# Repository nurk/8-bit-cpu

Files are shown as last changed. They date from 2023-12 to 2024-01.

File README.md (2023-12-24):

This repository contains my design of the Ben Eater 8-bit computer.  I call it an 8-CPU instead of a computer because to me it feels more like a CPU.

If you were to do a checkout of this, it is basically a KiCad project folder.  It will not contain all the symbols I used because the ones I designed I made global in KiCad, but I added a PDF of all the schematics.

You will also find my instruction set, the code to program the EEPROM's and the code to program the CPU which includes my test programs.

Below is a little badly written story of my journey.

## 8-bit CPU
I have always been intrigued by electronics by have never done anything with it.

A while back I found a video series by Ben Eater about building an 8-bit computer on breadboards ([YouTube](https://www.youtube.com/playlist?list=PLowKtXNTBypGqImE405J2565dvjafglHU)).  Watching the series I learned a lot about how CPU's (could) work and was really fascinated.  It all did not seem that complicated.

So after thinking about it for a while and checking my finances (It is not really cheap) I decided to build a variation of it.   But first I did some research and set some goals.

The research taught me that I should not skimp on breadboard quality.  There are a lot of people that write about this and the breadboards from BusBoard Prototype Systems seem to be one of the best.

Next I started digging into what types of 74 series logic chips there are.  I learned that the 74LS series that Ben uses are TTL logic chips but they are rather power hungry.  I decided I wanted to go with CMOS logic chips because they are more efficient.  In the end I went for 74HCT chips.  They are CMOS chips with TTL level support.  I went for this because I don't really know anything about this and I was not sure if I needed TTL level support in some parts.

So the chip series was decided and the breadboard brand was decided, now I needed a way to get all these things.  I started searching for those online and found the usual suspects: 
* Farnell
* Digikey
* Mouser
* ...

I live in Belgium so delivery costs, import taxes and VAT were important.  After a test order from [Mouser](https://www.mouser.be/) I learned that they take care of the VAT and the import taxes, and when you order over 50 EUR (excluding VAT) the delivery is free.  Just don't get caught at checkout because the prices on the site are without VAT.

I would also need a power supply.  I did not want to use a cut open USB cable but wanted some extra features.
* The device needed a global on/off switch
* I needed to be able to toggle the output on or off 
* Obviously the voltage should be settable
* The amperage should be limited
* I wanted over current protection so the output would be turned off if my creation would draw more than the set amps

On Amazon I found this [device](https://www.amazon.nl/dp/B0C1SMSW9F?ref=ppx_yo2ov_dt_b_product_details&th=1) that had all the features I wanted and it was not out of my budget.

Amazon was also used to buy the [wires](https://www.amazon.com.be/dp/B07V5FVSYL?psc=1&ref=ppx_yo2ov_dt_b_product_details) and initially some [resistors](https://www.amazon.com.be/dp/B0967TG6XR?ref=ppx_yo2ov_dt_b_product_details&th=1).  The wires were great and I ordered multiple of those because it seems this thing needs a lot of wire.  The resistors I hated and did not use.  The legs have a diameter of 0.3 mm which is just too thin.  When you want to insert them into a breadboard they just bend.  The resistors eventually also came from Mouser.

Next up, the goals of this build.
* I wanted a schematic of my build so I learned to use [KiCad](https://www.kicad.org/)
* Have more RAM so I could use all 8 address bits
* Have the RAM split so the first 128 bytes are for application memory and second 128 bytes are for data memory.  I did not want my application to overwrite itself
* Have an X register with +1 / -1 feature to enable specific loops and have it set the carry flag and zero flag
* Have a Stack
* Do not leave any input pins floating
* Have a 220 Ohm resistor on each LED (this includes each segment of the 7-segment display)
* Have a 100nF decoupling capacitor for each chip

The 220 Ohm resistor on each LED really made me think about component placement.  It dictated the layout on the breadboards.  Unlike what Ben does in his videos I could not just go from an output pin to ground.

After all the orders arrived I started building my CPU module by module in the order of the videos.  I would first design each module in KiCad and use my design to build it on breadboards.

While building I initially used 10k Ohm resistors to either pull-up or pull-down control signal pins.  That way I could use a jumper wire to switch its state without the pin being floating during the transition.  (The resistors were removed after wiring up the control signals.) The different modules were tested individually once they were finished.

When building the output module I noticed I did not order any 74HCT273 chips.  So I changed my design to use what I had which were 74HCT173 D-type flip flops.  In hindsight this seems to be a blessing in disguise because there seems to be a design issue with using the 74HCT273 as can be seen [here](https://www.youtube.com/playlist?list=PLyHdG0fm3K1j8sfvvdIarTFXVcFDdoBYp).

After finishing the clock, program counter, a register, alu, b register, output, ram and instruction register I decided to combine them and wire them up to the bus.  This is were I got hit with my first problem.

Whenever there were more than 4 LED's active in the RAM value and I would change the RAM output control signal (high to low or low to high) the RAM address register would reset.  I searched for hours what the cause could be but never figured it out.  I rewired stuff, replaced chips, disconnected modules from the bus, added pull-up and pull-down resisters, ... but everything stayed the same.  Motivation really sank so drastic measures needed to be taken.  Given the RAM address gets loaded by the program counter initially I decided I did not need a reset there and removed the reset line and tied the pins to ground.  *Problem solved*.

Next I built the last 4 modules: control logic, CPU flags, X register and stack.  When they were done I wired up everything.  Guess what, things did not work as expected.  Some of the problems I saw:
* The A register would reset randomly
* The X register would reset randomly
* The X register would load data from the bus at random points
* The X register would increment and decrement randomly
* The stack would increment and decrement randomly
* RAM not always writing

Those dreaded random resets were spreading.  Given I have no oscilloscope I could not really see what was going on with reset line but after some mental gymnastics I figured there must be some noise getting to the reset line.  Given I know nothing about electronics I started trying things.  

When I put a 10nF capacitor on the reset line close to the reset pin and ground of the A register it no longer did the random reset but the button to reset everything still worked.  I did the same with the X register and wired up the reset for the RAM address again with a 10nF capacitor.  No more random resets.  I still don't know why this is happening but it is fixed.  *Problem solved*.

Next up were the random actions in the X register and stack.  After searching the internet I found out that when you change the address on an EEPROM there is a period of time where the data is invalid (this is also in the datasheet).  This shows itself by data pins going high or low randomly during the invalid period.  This was triggering the random actions.

The first fix was not to trigger the load of the X register by just using an inverted control signal.  I used the non inverted control signal and the clock through a NAND gate to trigger the load.  This way the loading is tied to a clock transition which is in line with the rest of the design.  This made things better but did not solve everything.

After some more searching on the internet I found a post where someone explained that the entire computer reacts to the rising edge of the clock.  This includes the instruction register and the CPU flags which trigger address changes.  If you were to change the address on the falling edge of the clock the 'blips' on the EEPROM output would not matter.

I first thought about using the inverted clock for the instruction register and the CPU flags but decided against it.  I was not sure if this would have side effects.  Given I had some room below the instruction register I decided to add two more 74HCT173 D-type flip flops to latch the instruction register and the CPU flags on the falling edge of each clock.  These latched values are used as the address lines for the EEPROM's.  This solved all the problems of random actions occurring.

Lastly there was the problem of the RAM not always writing.  I was aware of issues with the RC circuit Ben has in his original design on the clock for the RAM input.  I already put in a diode to prevent back feeding any voltage as the capacitor discharges but I was still suspicious.  Given writing ram works with a push button in programming mode, which does not have an RC circuit on it, I figured it might work without.  After removing the RC circuit and just passing in the clock everything worked.

I now have an 8-bit breadboard CPU which supports addition, subtraction, push, pop, subroutines, ...

#### Some random bits:

I can program the CPU using the dip switches but that got old really quickly.  I wrote a little Arduino application that could program the CPU.  I just hook up the ground, the address lines, the data lines and write signal to the breadboard from an [Arduino Nano Every](https://store.arduino.cc/products/arduino-nano-every).  This saves a lot of time and does not discourage me from making changes and retesting.

On the internet there are many posts that say you have to add a lot of bulk capacitors to the breadboards in order to make it stable.  My CPU does not seem to need it.  It could be the quality of the breadboards, the fact that I used 74HCT chips or the quality of the power supply.  When running my Fibonacci program it draws a maximum of 350 mA.

I used an alternative to the EEPROM programmer designed by Ben.  Given I used an Arduino Nano Every, which has more digital pins, I did not have to combine the write signal into the shift registers.  I did have to rewire it because my EEPROM's did not seems to have the content I expected. 

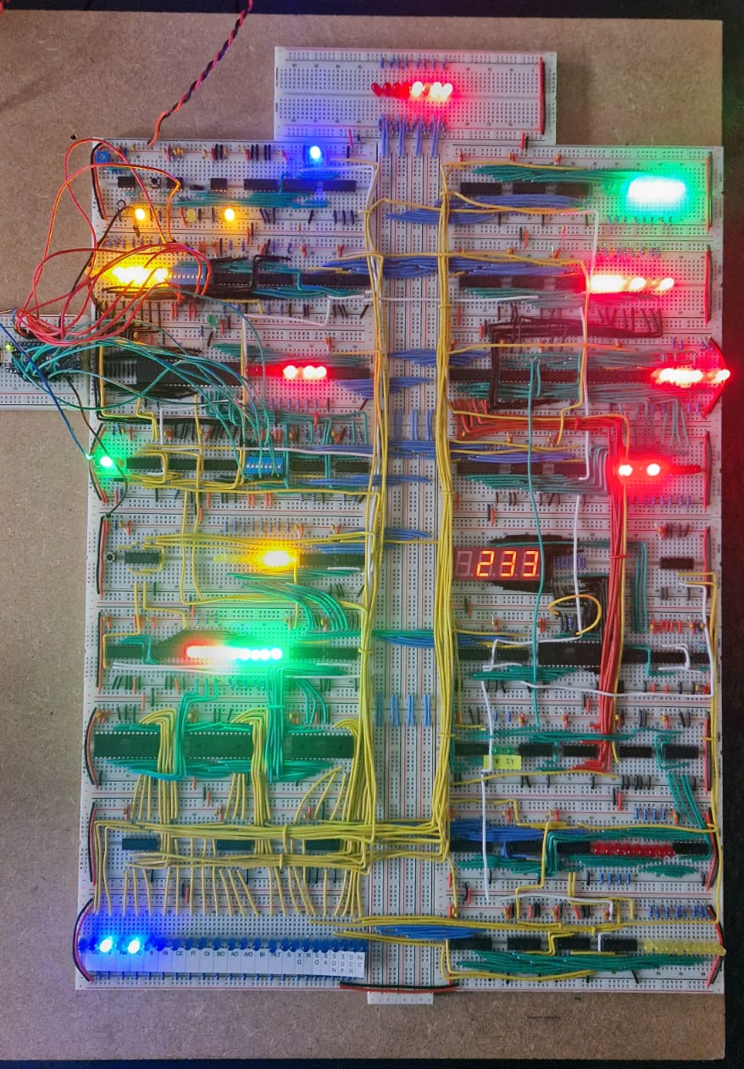
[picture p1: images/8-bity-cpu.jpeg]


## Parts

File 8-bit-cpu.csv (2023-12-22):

Source: | /Users/tom/Documents/KiCad/7.0/projects/8-bit-cpu/8-bit-cpu.kicad_sch
Date: | 2023-11-28
Tool: | Eeschema 7.0.9
Generator: | /Applications/KiCad/KiCad.app/Contents/SharedSupport/plugins/bom_csv_grouped_by_value.py
Component Count: | 440
Collated Components:
Item | Qty | Reference(s) | Value | LibPart | Footprint | Datasheet | DNP
1 | 66 | C1, C2, C3, C4, C7, C9, C10, C11, C14, C15, C16, C17, C18, C19, C20, C21, C22, C23, C24, C25, C26, C28, C29, C30, C31, C32, C33, C34, C35, C36, C37, C38, C39, C40, C41, C42, C45, C46, C47, C48, C49, C50, C51, C52, C53, C54, C55, C56, C57, C58, C59, C60, C61, C62, C63, C64, C65, C66, C67, C68, C69, C70, C71, C73, C74, C75 | 100n | Device:C | 01_my_library:C_Disc_D4.0mm_W2.6mm_P2.50mm | ~
2 | 1 | C5 | 1u | Device:C_Polarized | Capacitor_THT:CP_Radial_D5.0mm_P2.00mm | ~
3 | 5 | C6, C8, C12, C43, C44 | 10n | Device:C | 01_my_library:C_Disc_D4.0mm_W2.6mm_P2.50mm | ~
4 | 3 | C13, C27, C72 | 10n | Device:C | 01_my_library:C_Disc_D4.0mm_W2.6mm_P2.50mm | ~ | DNP
5 | 52 | D1, D2, D3, D4, D5, D6, D7, D8, D13, D14, D15, D16, D17, D18, D19, D20, D21, D22, D23, D24, D25, D26, D27, D28, D29, D30, D31, D32, D33, D34, D35, D36, D37, D38, D39, D40, D41, D42, D43, D44, D55, D72, D73, D74, D107, D108, D109, D110, D111, D112, D113, D114 | RED | Device:LED | LED_THT:LED_D5.0mm | ~
6 | 28 | D9, D10, D12, D45, D46, D47, D48, D49, D50, D51, D52, D53, D64, D65, D66, D67, D68, D69, D70, D71, D115, D116, D117, D118, D119, D120, D121, D122 | YELLOW | Device:LED | LED_THT:LED_D5.0mm | ~
7 | 25 | D11, D81, D82, D83, D84, D85, D86, D87, D88, D89, D90, D91, D92, D93, D94, D95, D96, D97, D98, D99, D100, D101, D102, D103, D104 | BLUE | Device:LED | LED_THT:LED_D5.0mm | ~
8 | 17 | D54, D56, D57, D58, D59, D60, D61, D62, D63, D75, D76, D77, D78, D79, D80, D105, D106 | GREEN | Device:LED | LED_THT:LED_D5.0mm | ~
9 | 1 | J1 | Arduino_Address_Programming_Header | Connector:Conn_01x09_Socket | Connector_PinSocket_2.54mm:PinSocket_1x09_P2.54mm_Vertical | ~
10 | 1 | J2 | Arduino_Data_Programming_Header | Connector:Conn_01x09_Socket | Connector_PinSocket_2.54mm:PinSocket_1x09_P2.54mm_Vertical | ~
11 | 1 | J3 | Arduino_Programming_Trigger_Header | Connector:Conn_01x02_Socket | Connector_PinSocket_2.54mm:PinSocket_1x02_P2.54mm_Vertical | ~
12 | 1 | J4 | 2_Complement_Header | Connector:Conn_01x02_Socket | Connector_PinSocket_2.54mm:PinSocket_1x02_P2.54mm_Vertical | ~
13 | 130 | R1, R2, R3, R4, R5, R6, R7, R8, R17, R21, R23, R26, R27, R28, R29, R30, R31, R32, R33, R34, R35, R36, R37, R38, R39, R40, R41, R42, R43, R44, R45, R46, R47, R48, R49, R50, R51, R52, R53, R54, R55, R56, R57, R58, R67, R68, R69, R70, R71, R72, R73, R74, R75, R84, R85, R88, R89, R90, R91, R92, R93, R94, R95, R98, R99, R100, R101, R102, R103, R104, R105, R107, R108, R109, R110, R111, R112, R113, R114, R116, R117, R118, R119, R120, R121, R122, R123, R124, R125, R126, R127, R128, R129, R130, R131, R132, R133, R134, R135, R136, R137, R138, R139, R140, R141, R142, R143, R144, R145, R146, R147, R148, R149, R150, R151, R152, R153, R154, R155, R156, R157, R158, R159, R160, R161, R162, R163, R164, R165, R166 | 220R | Device:R | Resistor_THT:R_Axial_DIN0204_L3.6mm_D1.6mm_P7.62mm_Horizontal | ~
14 | 31 | R9, R10, R11, R12, R13, R14, R15, R16, R20, R24, R25, R59, R60, R61, R62, R63, R64, R65, R66, R76, R77, R78, R79, R80, R81, R82, R83, R86, R87, R106, R115 | 10k | Device:R | Resistor_THT:R_Axial_DIN0204_L3.6mm_D1.6mm_P7.62mm_Horizontal | ~
15 | 3 | R18, R19, R96 | 1k | Device:R | Resistor_THT:R_Axial_DIN0204_L3.6mm_D1.6mm_P7.62mm_Horizontal | ~
16 | 1 | R22 | 1m | Device:R | Resistor_THT:R_Axial_DIN0204_L3.6mm_D1.6mm_P7.62mm_Horizontal | ~
17 | 1 | R97 | 100k | Device:R | Resistor_THT:R_Axial_DIN0204_L3.6mm_D1.6mm_P7.62mm_Horizontal | ~
18 | 1 | RV1 | 1m | Device:R_Potentiometer | 01_my_library:Potentiometer_Bourns_3362U_Vertical | ~
19 | 3 | SW1, SW6, SW7 | Button | Switch:SW_Push | Button_Switch_THT:SW_PUSH_6mm | ~
20 | 1 | SW2 | Switch | Switch:SW_SPDT | 01_my_library:Mini_Slide_Switch_CUI_THT_123 | ~
21 | 2 | SW3, SW4 | SW_DIP_x08 | Switch:SW_DIP_x08 | Button_Switch_THT:SW_DIP_SPSTx08_Slide_9.78x22.5mm_W7.62mm_P2.54mm | ~
22 | 1 | SW5 | Programming Switch | Switch:SW_SPDT | 01_my_library:Mini_Slide_Switch_CUI_THT_123 | ~
23 | 3 | U1, U53, U55 | 74HCT08 | 74xx:74LS08 | Package_DIP:DIP-14_W7.62mm | http://www.ti.com/lit/gpn/sn74LS08
24 | 1 | U2 | 74HCT04 | 74xx:74LS04 | Package_DIP:DIP-14_W7.62mm | http://www.ti.com/lit/gpn/sn74LS04
25 | 1 | U3 | 74HCT32 | 74xx:74LS32 | Package_DIP:DIP-14_W7.62mm | http://www.ti.com/lit/gpn/sn74LS32
26 | 4 | U4, U5, U6, U34 | LMC555xN | Timer:LMC555xN | Package_DIP:DIP-8_W7.62mm | http://www.ti.com/lit/ds/symlink/lmc555.pdf
27 | 7 | U7, U10, U15, U18, U29, U60, U63 | 74HCT245 | 01_my_library:74HCT245 | Package_DIP:DIP-20_W7.62mm | https://www.ti.com/lit/ds/symlink/sn74hct245.pdf?ts=1702763405638
28 | 13 | U8, U9, U11, U12, U20, U21, U36, U38, U39, U40, U42, U43, U57 | 74HCT173 | 74xx:74LS173 | Package_DIP:DIP-16_W7.62mm | http://www.ti.com/lit/gpn/sn74LS173
29 | 2 | U13, U14 | 74HCT86 | 74xx:74HC86 | Package_DIP:DIP-14_W7.62mm | http://www.ti.com/lit/gpn/sn74HC86
30 | 2 | U16, U17 | 74HCT283 | 01_my_library:74HCT283 | Package_DIP:DIP-16_W7.62mm | https://www.ti.com/lit/ds/symlink/cd54hct283.pdf?ts=1702794975080
31 | 1 | U19 | 7130 | 01_my_library:7130SA/LA | Package_DIP:DIP-48_W15.24mm | https://www.mouser.be/datasheet/2/698/REN_7130_DST_20210712-1996079.pdf
32 | 7 | U22, U23, U24, U25, U27, U28, U54 | 74HCT157 | 01_my_library:74HCT157 | Package_DIP:DIP-16_W7.62mm | https://www.ti.com/lit/ds/symlink/sn74hct157.pdf
33 | 4 | U26, U41, U58, U59 | 74HCT00 | 74xx:74HCT00 | Package_DIP:DIP-14_W7.62mm | http://www.ti.com/lit/gpn/sn74hct00
34 | 3 | U30, U31, U45 | 74HCT161 | 01_my_library:74HCT161 | Package_DIP:DIP-16_W7.62mm | https://www.ti.com/lit/ds/symlink/cd54hct163.pdf?HQS=dis-mous-null-mousermode-dsf-pf-null-wwe&ts=1702794645288
35 | 1 | U32 | 74HCT107 | :74LS107_2 | Package_DIP:DIP-14_W7.62mm | http://www.ti.com/lit/gpn/sn74LS107
36 | 1 | U33 | 74HCT139 | 01_my_library:74HCT139 | Package_DIP:DIP-16_W7.62mm | https://www.ti.com/lit/ds/symlink/sn74hct139.pdf?ts=1702741591478
37 | 1 | U35 | LTC-5723HR | Display_Character:CC56-12SURKWA | Display_7Segment:CA56-12SURKWA | http://www.kingbright.com/attachments/file/psearch/000/00/00/CC56-12SURKWA(Ver.7A).pdf
38 | 4 | U37, U47, U49, U51 | AT28C64B | 01_my_library:28C64B | Package_DIP:DIP-28_W15.24mm_Socket
39 | 1 | U44 | 74HCT138 | 01_my_library:74HCT138 | Package_DIP:DIP-16_W7.62mm | https://www.ti.com/lit/ds/symlink/sn54hct138.pdf?ts=1702793331407
40 | 3 | U46, U48, U50 | 74HCT04 | 74xx:74HCT04 | Package_DIP:DIP-14_W7.62mm | https://assets.nexperia.com/documents/data-sheet/74HC_HCT04.pdf
41 | 2 | U52, U56 | 74HCT02 | 74xx:74HCT02 | Package_DIP:DIP-14_W7.62mm | http://www.ti.com/lit/gpn/sn74hct02
42 | 4 | U61, U62, U64, U65 | 74HCT193 | 01_my_library:74HCT193 | Package_DIP:DIP-16_W7.62mm | https://www.ti.com/lit/ds/symlink/cd74hct193.pdf?HQS=dis-mous-null-mousermode-dsf-pf-null-wwe&ts=1702791971938

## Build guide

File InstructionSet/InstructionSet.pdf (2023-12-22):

### Micro code EEPROM layout

| Instruction code | Step | Flags | Left | Direct | To inverters | Middle | Direct | To inverters | Right
CF | ZF | | CE | RI | RaI | RO | II | J | CO | AI | | S | HLT | AO | AlO | BI | BO | OI | FI | | INC | DCR | SUP | SDN | SA | SO | XI | XO
A8 | A7 | A6 | A5 | A4 | A3 | A2 | A1 | A0 | A9 | A10 | A11 | A12 | D7 | D6 | Y5 | Y4 | Y3 | Y2 | Y1 | Y0 | A11 | A12 | D7 | D6 | Y5 | Y4 | Y3 | Y2 | Y1 | Y0 | A11 | A12 | D7 | D6 | D5 | D4 | D3 | Y2 | D1 | Y0
NOP Is also the start of each instruction | 0 | 0 | 0 | 0 | 0 | 0 | 0 | 0 | 0 | X | X | 0 | 0 | | | 1 | | | | 1 | | 0 | 1 | | | | | | | | | 1 | 0
| | | | | | | 0 | 0 | 1 | X | X | 0 | 0 | 1 | | | 1 | 1 | | | | 0 | 1 | | | | | | | | | 1 | 0
LDA | 0 | 0 | 0 | 0 | 0 | 1 | 0 | 1 | 0 | X | X | 0 | 0 | | | 1 | | | | 1 | | 0 | 1 | | | | | | | | | 1 | 0
| | | | | | | 0 | 1 | 1 | X | X | 0 | 0 | 1 | | 1 | 1 | | | | | 0 | 1 | | | | | | | | | 1 | 0
| | | | | | | 1 | 0 | 0 | X | X | 0 | 0 | | | | 1 | | | | 1 | 0 | 1 | | | | | | | | | 1 | 0
ADD Add what is at memory address to A | 0 | 0 | 0 | 0 | 1 | 0 | 0 | 1 | 0 | X | X | 0 | 0 | | | 1 | | | | 1 | | 0 | 1 | | | | | | | | | 1 | 0
| | | | | | | 0 | 1 | 1 | X | X | 0 | 0 | 1 | | 1 | 1 | | | | | 0 | 1 | | | | | | | | | 1 | 0
| | | | | | | 1 | 0 | 0 | X | X | 0 | 0 | | | | 1 | | | | | 0 | 1 | | | | | 1 | | | | 1 | 0
| | | | | | | 1 | 0 | 1 | X | X | 0 | 0 | | | | | | | | 1 | 0 | 1 | | | | 1 | | | | 1 | 1 | 0
SUB Subtract what is at memory address from A | 0 | 0 | 0 | 0 | 1 | 1 | 0 | 1 | 0 | X | X | 0 | 0 | | | 1 | | | | 1 | | 0 | 1 | | | | | | | | | 1 | 0
| | | | | | | 0 | 1 | 1 | X | X | 0 | 0 | 1 | | 1 | 1 | | | | | 0 | 1 | | | | | | | | | 1 | 0
| | | | | | | 1 | 0 | 0 | X | X | 0 | 0 | | | | 1 | | | | | 0 | 1 | | | | | 1 | | | | 1 | 0
| | | | | | | 1 | 0 | 1 | X | X | 0 | 0 | | | | | | | | 1 | 0 | 1 | 1 | | | 1 | | | | 1 | 1 | 0
STA | 0 | 0 | 0 | 1 | 0 | 0 | 0 | 1 | 0 | X | X | 0 | 0 | | | 1 | | | | 1 | | 0 | 1 | | | | | | | | | 1 | 0
| | | | | | | 0 | 1 | 1 | X | X | 0 | 0 | 1 | | 1 | 1 | | | | | 0 | 1 | | | | | | | | | 1 | 0
| | | | | | | 1 | 0 | 0 | X | X | 0 | 0 | | 1 | | | | | | | 0 | 1 | | | 1 | | | | | | 1 | 0
LDI Load direct into A | 0 | 0 | 0 | 1 | 0 | 1 | 0 | 1 | 0 | X | X | 0 | 0 | | | 1 | | | | 1 | | 0 | 1 | | | | | | | | | 1 | 0
| | | | | | | 0 | 1 | 1 | X | X | 0 | 0 | 1 | | | 1 | | | | 1 | 0 | 1 | | | | | | | | | 1 | 0
JMP Jump to address | 0 | 0 | 0 | 1 | 1 | 0 | 0 | 1 | 0 | X | X | 0 | 0 | | | 1 | | | | 1 | | 0 | 1 | | | | | | | | | 1 | 0
| | | | | | | 0 | 1 | 1 | X | X | 0 | 0 | | | | 1 | | 1 | | | 0 | 1 | | | | | | | | | 1 | 0
JC Jump to address if carry out | 0 | 0 | 0 | 1 | 1 | 1 | 0 | 1 | 0 | X | X | 0 | 0 | | | 1 | | | | 1 | | 0 | 1 | | | | | | | | | 1 | 0
| | | | | | | 0 | 1 | 1 | 0 | X | 0 | 0 | 1 | | | | | | | | 0 | 1 | | | | | | | | | 1 | 0
| | | | | | | 0 | 1 | 1 | 1 | X | 0 | 0 | | | | 1 | | 1 | | | 0 | 1 | | | | | | | | | 1 | 0
JZ Jump to address if zero | 0 | 0 | 1 | 0 | 0 | 0 | 0 | 1 | 0 | X | X | 0 | 0 | | | 1 | | | | 1 | | 0 | 1 | | | | | | | | | 1 | 0
| | | | | | | 0 | 1 | 1 | X | 0 | 0 | 0 | 1 | | | | | | | | 0 | 1 | | | | | | | | | 1 | 0
| | | | | | | 0 | 1 | 1 | X | 1 | 0 | 0 | | | | 1 | | 1 | | | 0 | 1 | | | | | | | | | 1 | 0
LDB | 0 | 0 | 1 | 0 | 0 | 1 | 0 | 1 | 0 | X | X | 0 | 0 | | | 1 | | | | 1 | | 0 | 1 | | | | | | | | | 1 | 0
| | | | | | | 0 | 1 | 1 | X | X | 0 | 0 | 1 | | 1 | 1 | | | | | 0 | 1 | | | | | | | | | 1 | 0
| | | | | | | 1 | 0 | 0 | X | X | 0 | 0 | | | | 1 | | | | | 0 | 1 | | | | | 1 | | | | 1 | 0
STB | 0 | 0 | 1 | 0 | 1 | 0 | 0 | 1 | 0 | X | X | 0 | 0 | 1 | 1 | 0 | 1 | 1 | 0
0 | 1 | 1 | X | X | 0 | 0 | 1 | 1 | 1 | 0 | 1 | 1 | 0

| Instruction code | Step | Flags | Left | Direct | To inverters | Middle | Direct | To inverters | Right
CF | ZF | | CE | RI | RaI | RO | II | J | CO | AI | | S | HLT | AO | AlO | BI | BO | OI | FI | | INC | DCR | SUP | SDN | SA | SO | XI | XO
A8 | A7 | A6 | A5 | A4 | A3 | A2 | A1 | A0 | A9 | A10 | A11 | A12 | D7 | D6 | Y5 | Y4 | Y3 | Y2 | Y1 | Y0 | A11 | A12 | D7 | D6 | Y5 | Y4 | Y3 | Y2 | Y1 | Y0 | A11 | A12 | D7 | D6 | D5 | D4 | D3 | Y2 | D1 | Y0
| | | | | | | 1 | 0 | 0 | X | X | 0 | 0 | | 1 | | | | | | | 0 | 1 | | | | | | 1 | | | 1 | 0
LDIB Load direct into B | 0 | 0 | 1 | 0 | 1 | 1 | 0 | 1 | 0 | X | X | 0 | 0 | | | 1 | | | | 1 | | 0 | 1 | | | | | | | | | 1 | 0
| | | | | | | 0 | 1 | 1 | X | X | 0 | 0 | 1 | | | 1 | | | | | 0 | 1 | | | | | 1 | | | | 1 | 0
OUT | 0 | 0 | 1 | 1 | 0 | 0 | 0 | 1 | 0 | X | X | 0 | 0 | | | | | | | | | 0 | 1 | | | 1 | | | | 1 | | 1 | 0
OUTB | 0 | 0 | 1 | 1 | 0 | 1 | 0 | 1 | 0 | X | X | 0 | 0 | | | | | | | | | 0 | 1 | | | | | | 1 | 1 | | 1 | 0
OUTX | 0 | 0 | 1 | 1 | 1 | 0 | 0 | 1 | 0 | X | X | 0 | 0 | | | | | | | | | 0 | 1 | | | | | | | 1 | | 1 | 0 | | | | | | | | 1
HLT | 0 | 0 | 1 | 1 | 1 | 1 | 0 | 1 | 0 | X | X | 0 | 0 | | | | | | | | | 0 | 1 | | 1 | | | | | | | 1 | 0
LDX | 0 | 1 | 0 | 0 | 0 | 0 | 0 | 1 | 0 | X | X | 0 | 0 | | | 1 | | | | 1 | | 0 | 1 | | | | | | | | | 1 | 0
| | | | | | | 0 | 1 | 1 | X | X | 0 | 0 | 1 | | 1 | 1 | | | | | 0 | 1 | | | | | | | | | 1 | 0
| | | | | | | 1 | 0 | 0 | X | X | 0 | 0 | | | | 1 | | | | | 0 | 1 | | | | | | | | | 1 | 0 | | | | | | | 1
STX | 0 | 1 | 0 | 0 | 0 | 1 | 0 | 1 | 0 | X | X | 0 | 0 | | | 1 | | | | 1 | | 0 | 1 | | | | | | | | | 1 | 0
| | | | | | | 0 | 1 | 1 | X | X | 0 | 0 | 1 | | 1 | 1 | | | | | 0 | 1 | | | | | | | | | 1 | 0
| | | | | | | 1 | 0 | 0 | X | X | 0 | 0 | | 1 | | | | | | | 0 | 1 | | | | | | | | | 1 | 0 | | | | | | | | 1
LDIX | 0 | 1 | 0 | 0 | 1 | 0 | 0 | 1 | 0 | X | X | 0 | 0 | | | 1 | | | | 1 | | 0 | 1 | | | | | | | | | 1 | 0
| | | | | | | 0 | 1 | 1 | X | X | 0 | 0 | 1 | | | 1 | | | | | 0 | 1 | | | | | | | | | 1 | 0 | | | | | | | 1
PSH | 0 | 1 | 0 | 0 | 1 | 1 | 0 | 1 | 0 | X | X | 0 | 0 | | | 1 | | | | | | 0 | 1 | | | | | | | | | 1 | 0 | | | | | 1 | 1
| | | | | | | 0 | 1 | 1 | X | X | 0 | 0 | | 1 | | | | | | | 0 | 1 | | | 1 | | | | | | 1 | 0 | | | 1 | | 1
POP | 0 | 1 | 0 | 1 | 0 | 0 | 0 | 1 | 0 | X | X | 0 | 0 | | | | | | | | | 0 | 1 | | | | | | | | | 1 | 0 | | | | 1
| | | | | | | 0 | 1 | 1 | X | X | 0 | 0 | | | 1 | | | | | | 0 | 1 | | | | | | | | | 1 | 0 | | | | | 1 | 1
| | | | | | | 1 | 0 | 0 | X | X | 0 | 0 | | | | 1 | | | | 1 | 0 | 1 | | | | | | | | | 1 | 0 | | | | | 1
PSHB | 0 | 1 | 0 | 1 | 0 | 1 | 0 | 1 | 0 | X | X | 0 | 0 | | | 1 | | | | | | 0 | 1 | | | | | | | | | 1 | 0 | | | | | 1 | 1
| | | | | | | 0 | 1 | 1 | X | X | 0 | 0 | | 1 | | | | | | | 0 | 1 | | | | | | 1 | | | 1 | 0 | | | 1 | | 1
POPB | 0 | 1 | 0 | 1 | 1 | 0 | 0 | 1 | 0 | X | X | 0 | 0 | | | | | | | | | 0 | 1 | | | | | | | | | 1 | 0 | | | | 1
| | | | | | | 0 | 1 | 1 | X | X | 0 | 0 | | | 1 | | | | | | 0 | 1 | | | | | | | | | 1 | 0 | | | | | 1 | 1
| | | | | | | 1 | 0 | 0 | X | X | 0 | 0 | | | | 1 | | | | | 0 | 1 | | | | | 1 | | | | 1 | 0 | | | | | 1
JSR | 0 | 1 | 0 | 1 | 1 | 1 | 0 | 1 | 0 | X | X | 0 | 0 | | | 1 | | | | | | 0 | 1 | | | | | | | | | 1 | 0 | | | | | 1 | 1
| | | | | | | 0 | 1 | 1 | X | X | 0 | 0 | | 1 | | | | | 1 | | 0 | 1 | | | | | | | | | 1 | 0 | | | 1 | | 1
| | | | | | | 1 | 0 | 0 | X | X | 0 | 0 | | | 1 | | | | 1 | | 0 | 1 | | | | | | | | | 1 | 0
| | | | | | | 1 | 0 | 1 | X | X | 0 | 0 | | | | 1 | | 1 | | | 0 | 1 | | | | | | | | | 1 | 0
RTS | 0 | 1 | 1 | 0 | 0 | 0 | 0 | 1 | 0 | X | X | 0 | 0 | | | | | | | | | 0 | 1 | | | | | | | | | 1 | 0 | | | | 1
| | | | | | | 0 | 1 | 1 | X | X | 0 | 0 | | | 1 | | | | | | 0 | 1 | | | | | | | | | 1 | 0 | | | | | 1 | 1
| | | | | | | 1 | 0 | 0 | X | X | 0 | 0 | | | | 1 | | 1 | | | 0 | 1 | | | | | | | | | 1 | 0 | | | | | 1
| | | | | | | 1 | 0 | 1 | X | X | 0 | 0 | 1 | | | | | | | | 0 | 1 | | | | | | | | | 1 | 0

| Instruction code | Step | Flags | Left | Direct | To inverters | Middle | Direct | To inverters | Right
CF | ZF | | CE | RI | RaI | RO | II | J | CO | AI | | S | HLT | AO | AlO | BI | BO | OI | FI | | INC | DCR | SUP | SDN | SA | SO | XI | XO
A8 | A7 | A6 | A5 | A4 | A3 | A2 | A1 | A0 | A9 | A10 | A11 | A12 | D7 | D6 | Y5 | Y4 | Y3 | Y2 | Y1 | Y0 | A11 | A12 | D7 | D6 | Y5 | Y4 | Y3 | Y2 | Y1 | Y0 | A11 | A12 | D7 | D6 | D5 | D4 | D3 | Y2 | D1 | Y0
INCX | 0 | 1 | 1 | 0 | 0 | 1 | 0 | 1 | 0 | X | X | 0 | 0 | | | | | | | | | 0 | 1 | | | | | | | | | 1 | 0 | 1
| | | | | | | 0 | 1 | 1 | X | X | 0 | 0 | | | | | | | | | 0 | 1 | | | | | | | | 1 | 1 | 0
DECX | 0 | 1 | 1 | 0 | 1 | 0 | 0 | 1 | 0 | X | X | 0 | 0 | | | | | | | | | 0 | 1 | | | | | | | | | 1 | 0 | | 1
| | | | | | | 0 | 1 | 1 | X | X | 0 | 0 | | | | | | | | | 0 | 1 | | | | | | | | 1 | 1 | 0
| | | | | | | | | | X | X | 0 | 0 | | | | | | | | | 0 | 1 | | | | | | | | | 1 | 0
| | | | | | | | | | X | X | 0 | 0 | | | | | | | | | 0 | 1 | | | | | | | | | 1 | 0
| | | | | | | | | | X | X | 0 | 0 | | | | | | | | | 0 | 1 | | | | | | | | | 1 | 0

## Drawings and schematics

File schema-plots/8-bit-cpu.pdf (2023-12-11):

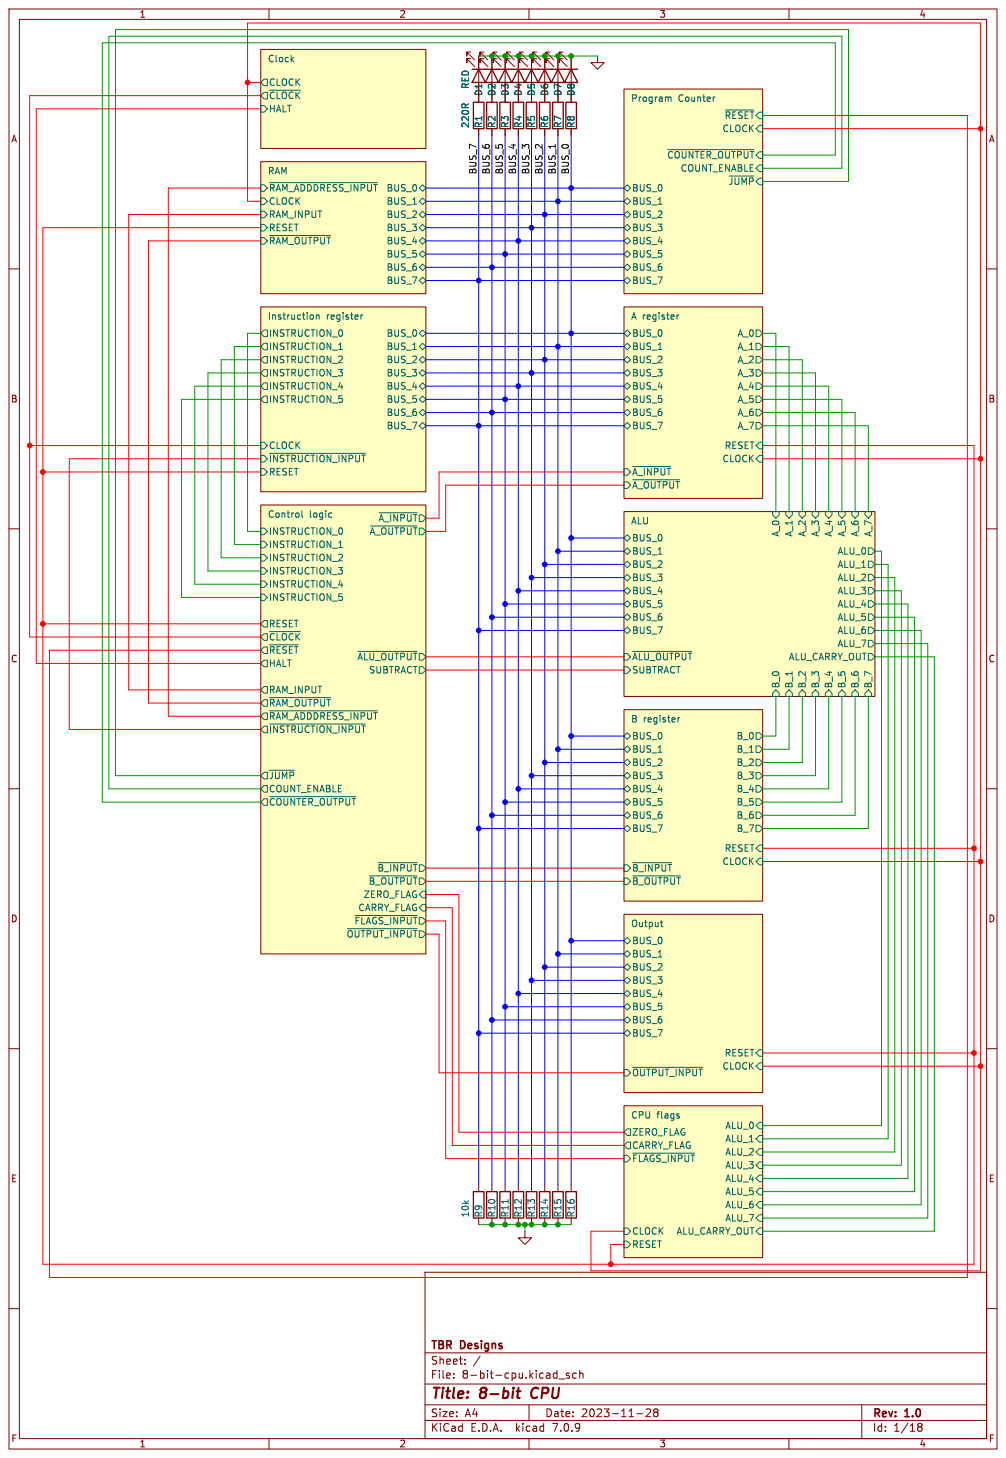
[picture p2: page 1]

Program Counter HALT CLOCK

~{FLAGS_INPUT} CLOCK RESET CPU flags
ZERO_FLAG

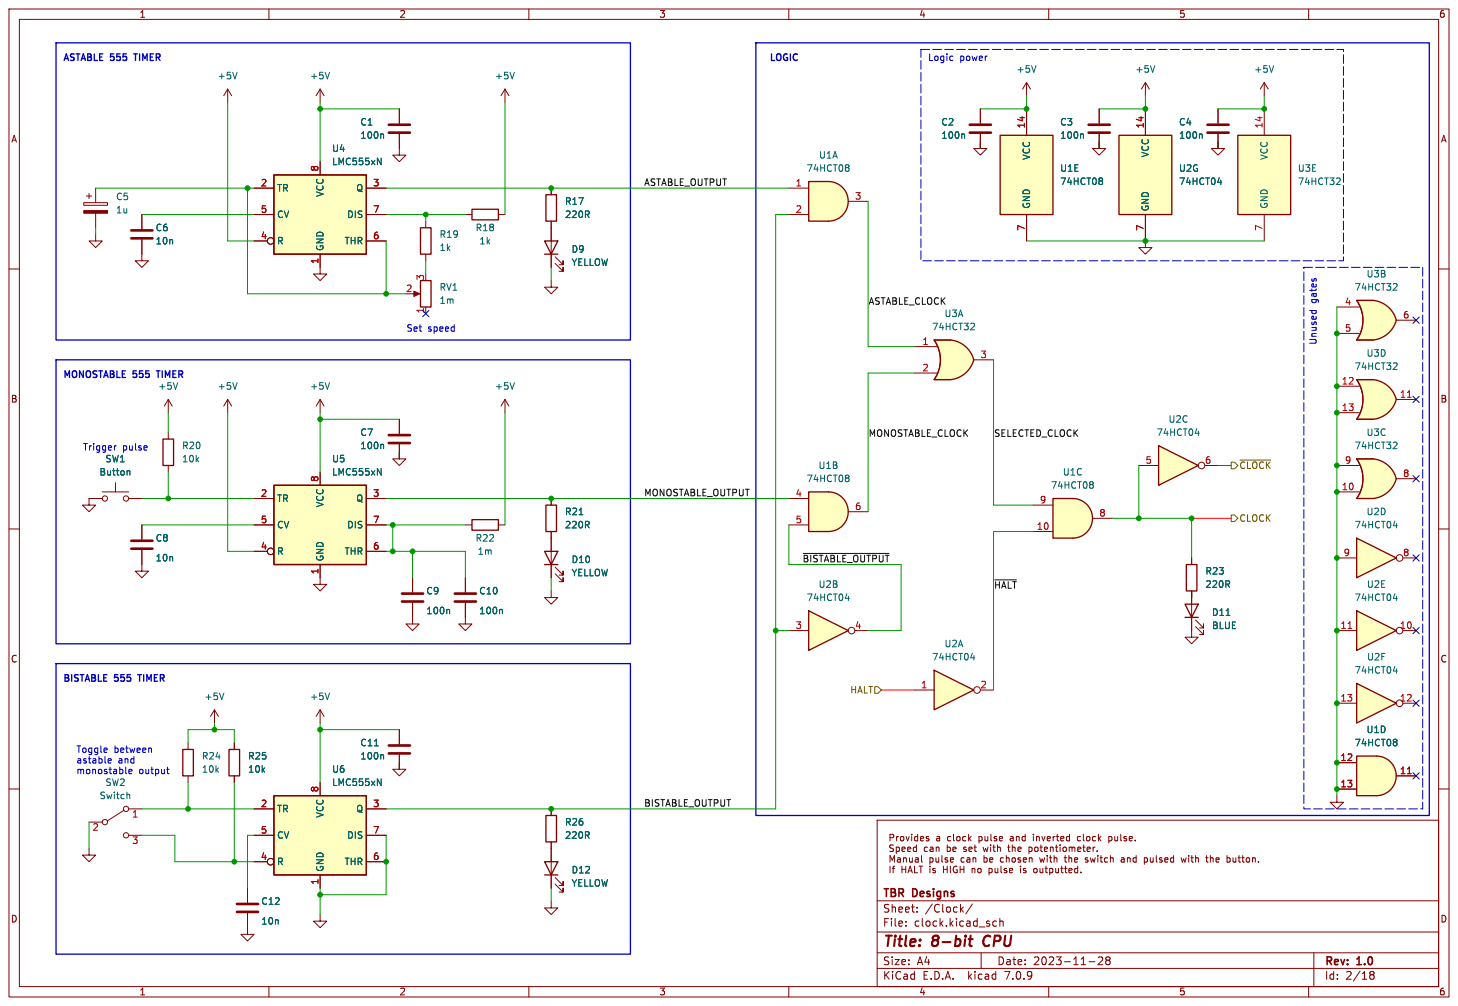
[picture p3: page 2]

Set speed ASTABLE 555 TIMER MONOSTABLE 555 TIMER

Speed can be set with the potentiometer. Manual pulse can be chosen with the switch and pulsed with the button.

If HALT is HIGH no pulse is outputted.

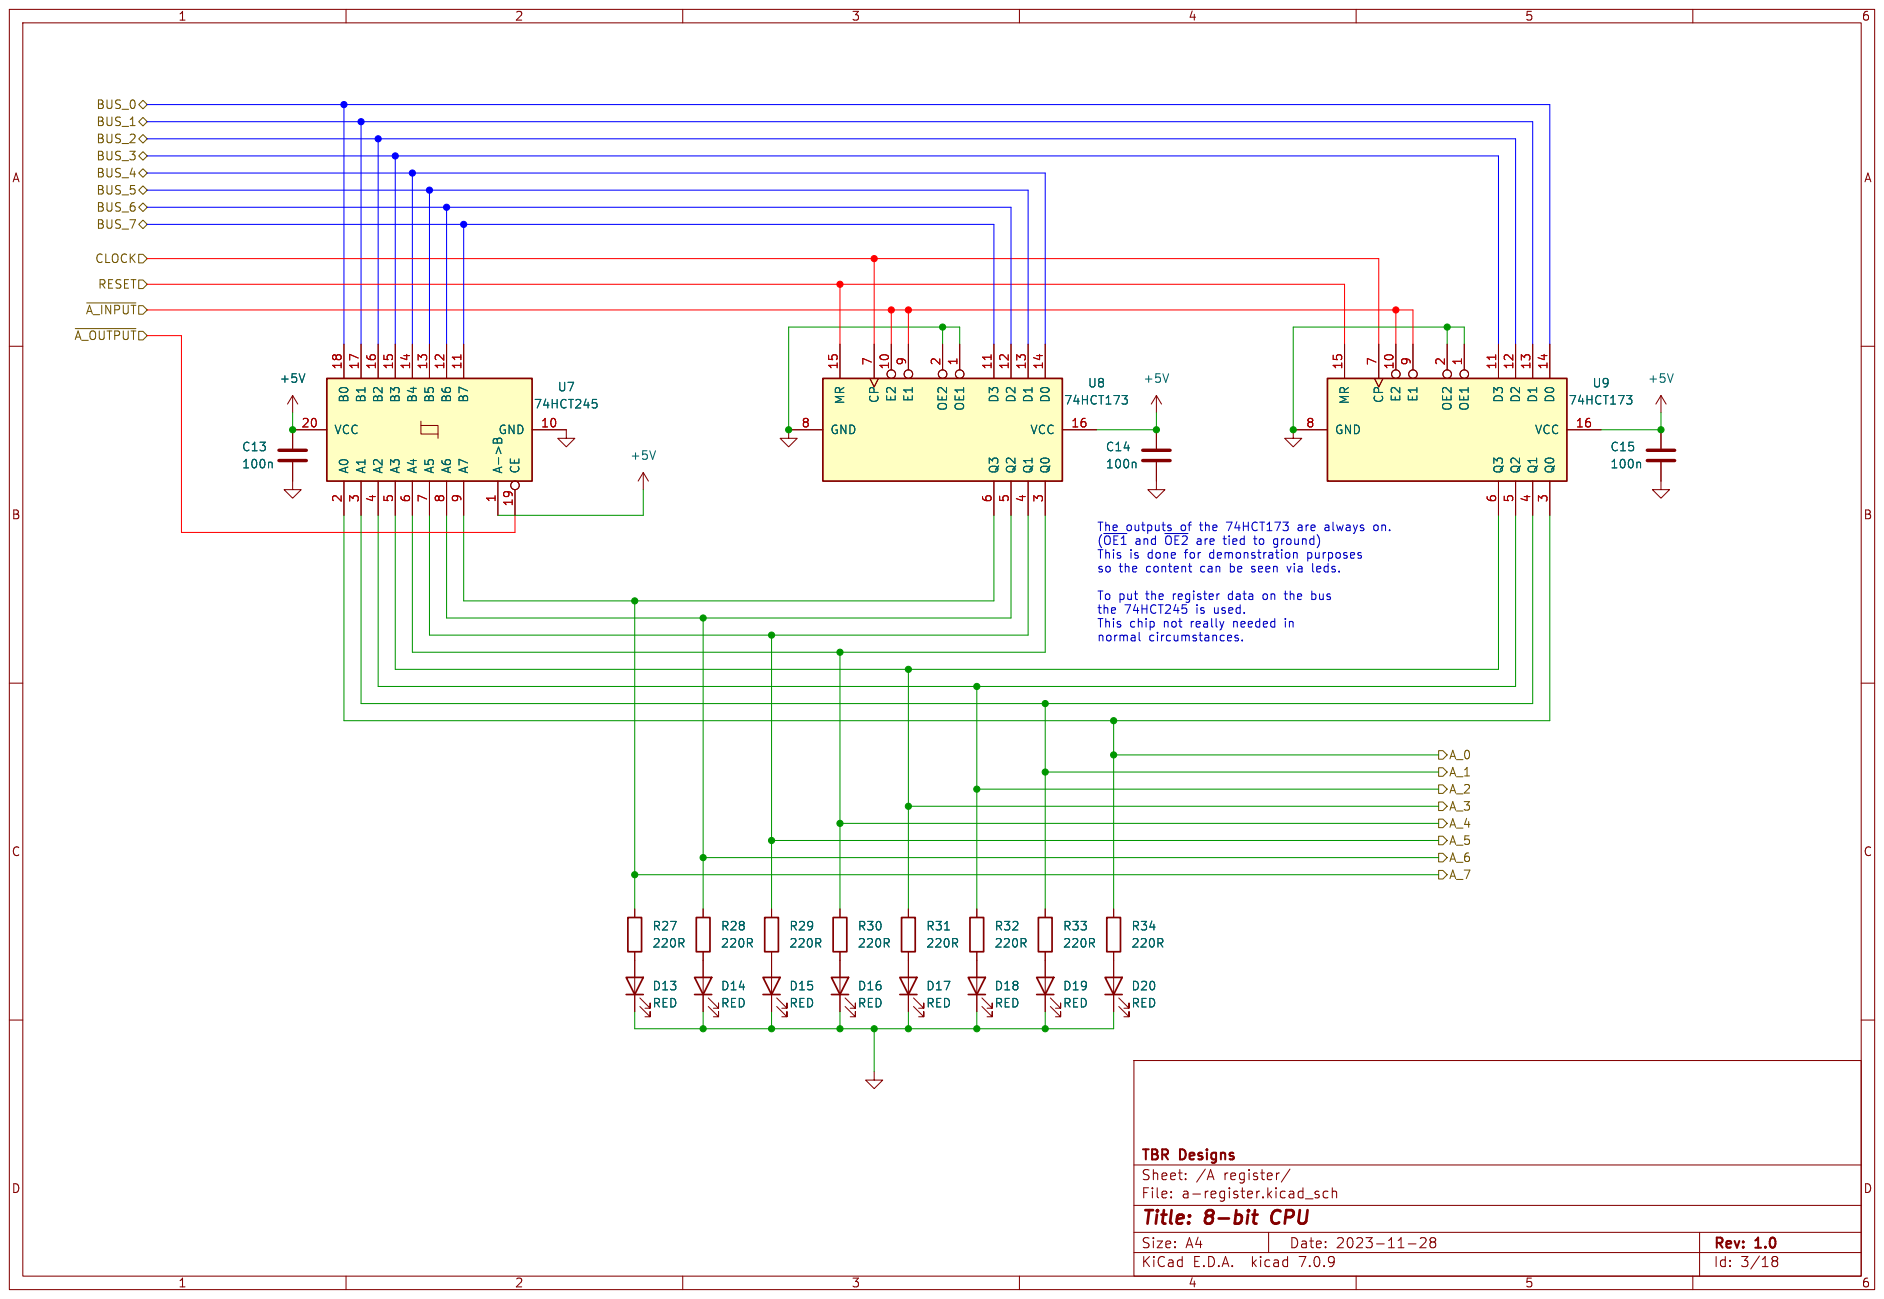
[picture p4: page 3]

the 74HCT245 is used. This chip not really needed in

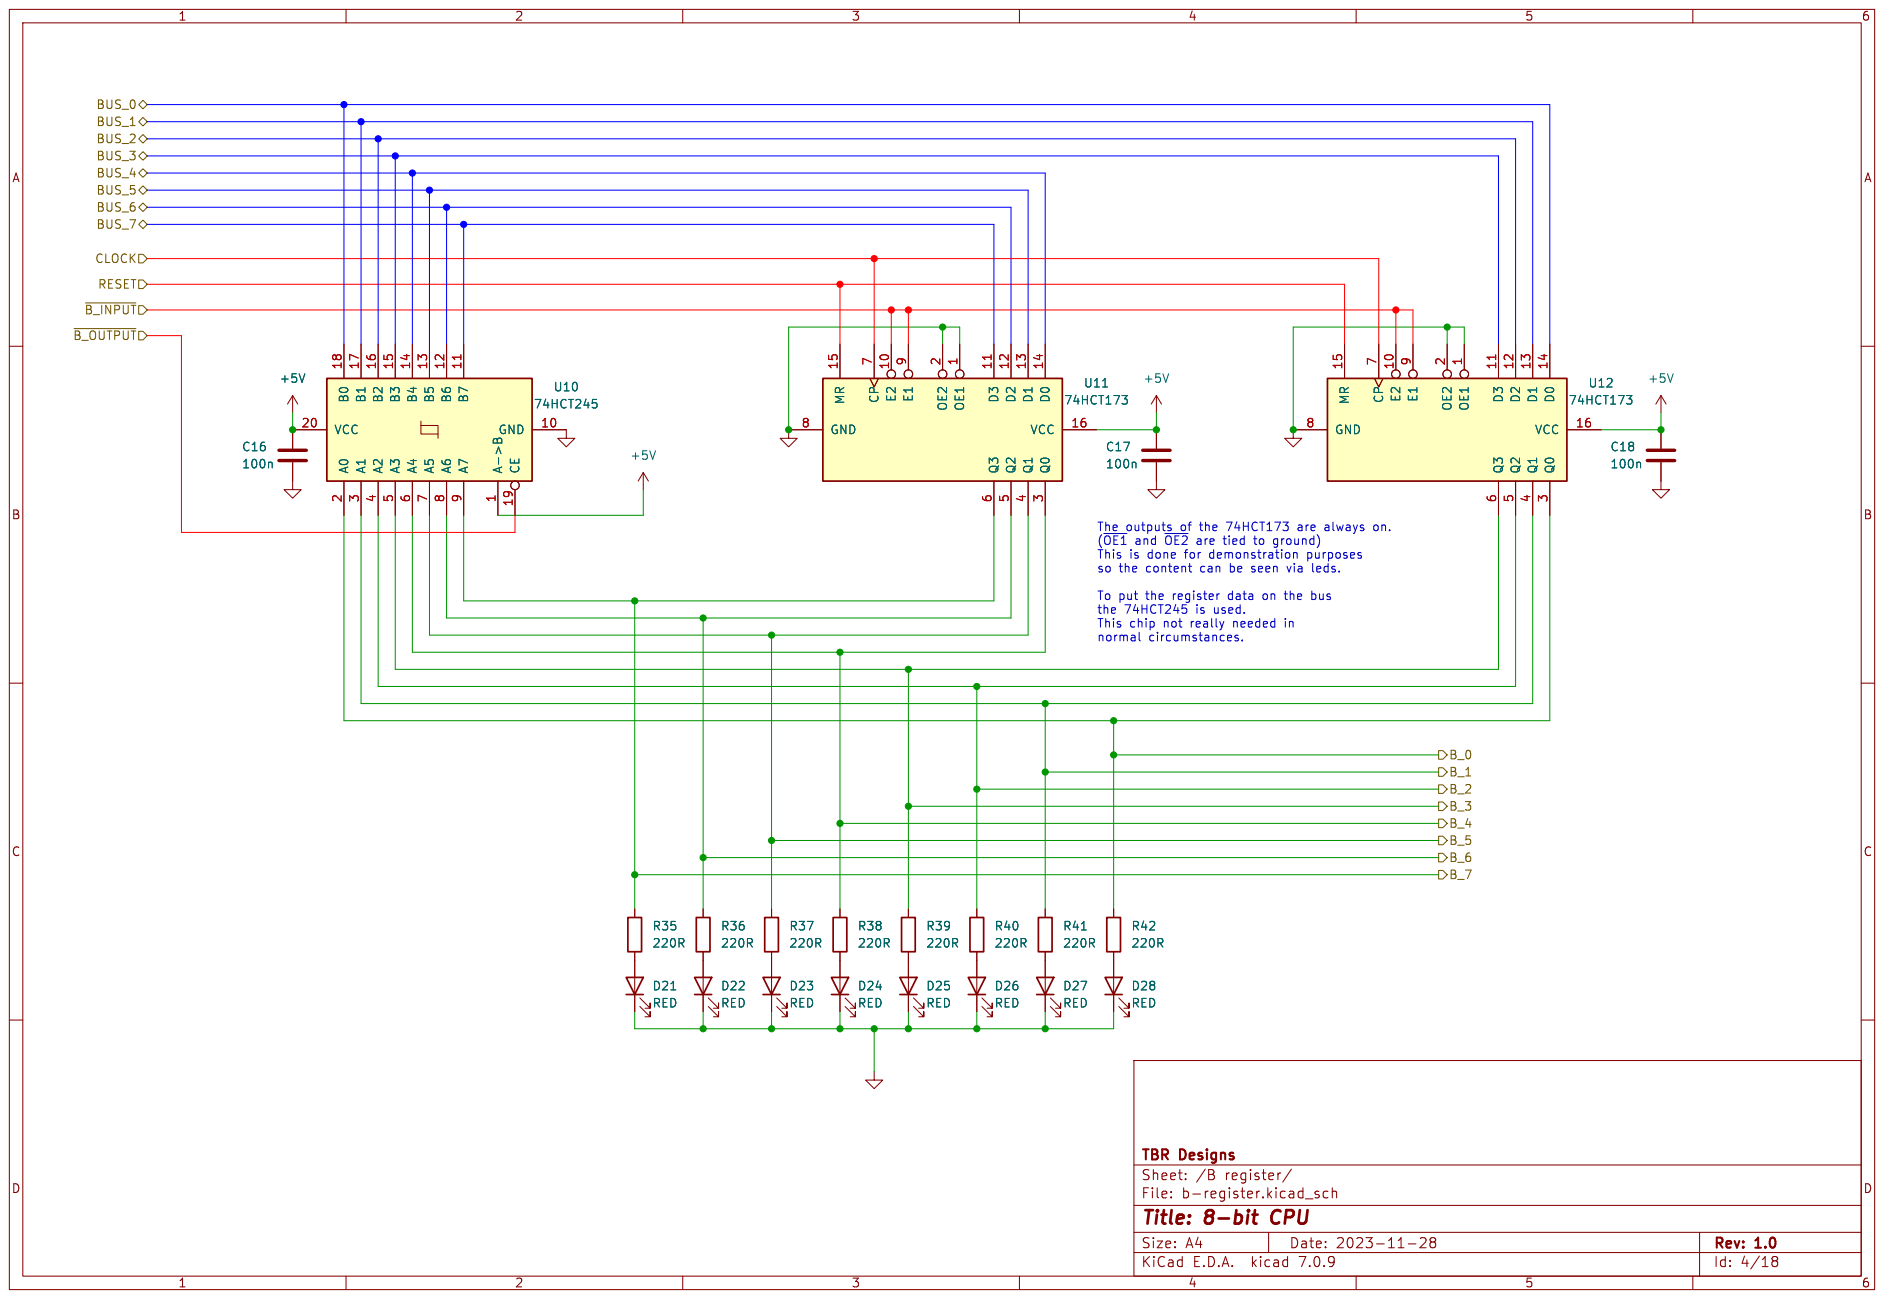
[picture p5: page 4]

the 74HCT245 is used. This chip not really needed in

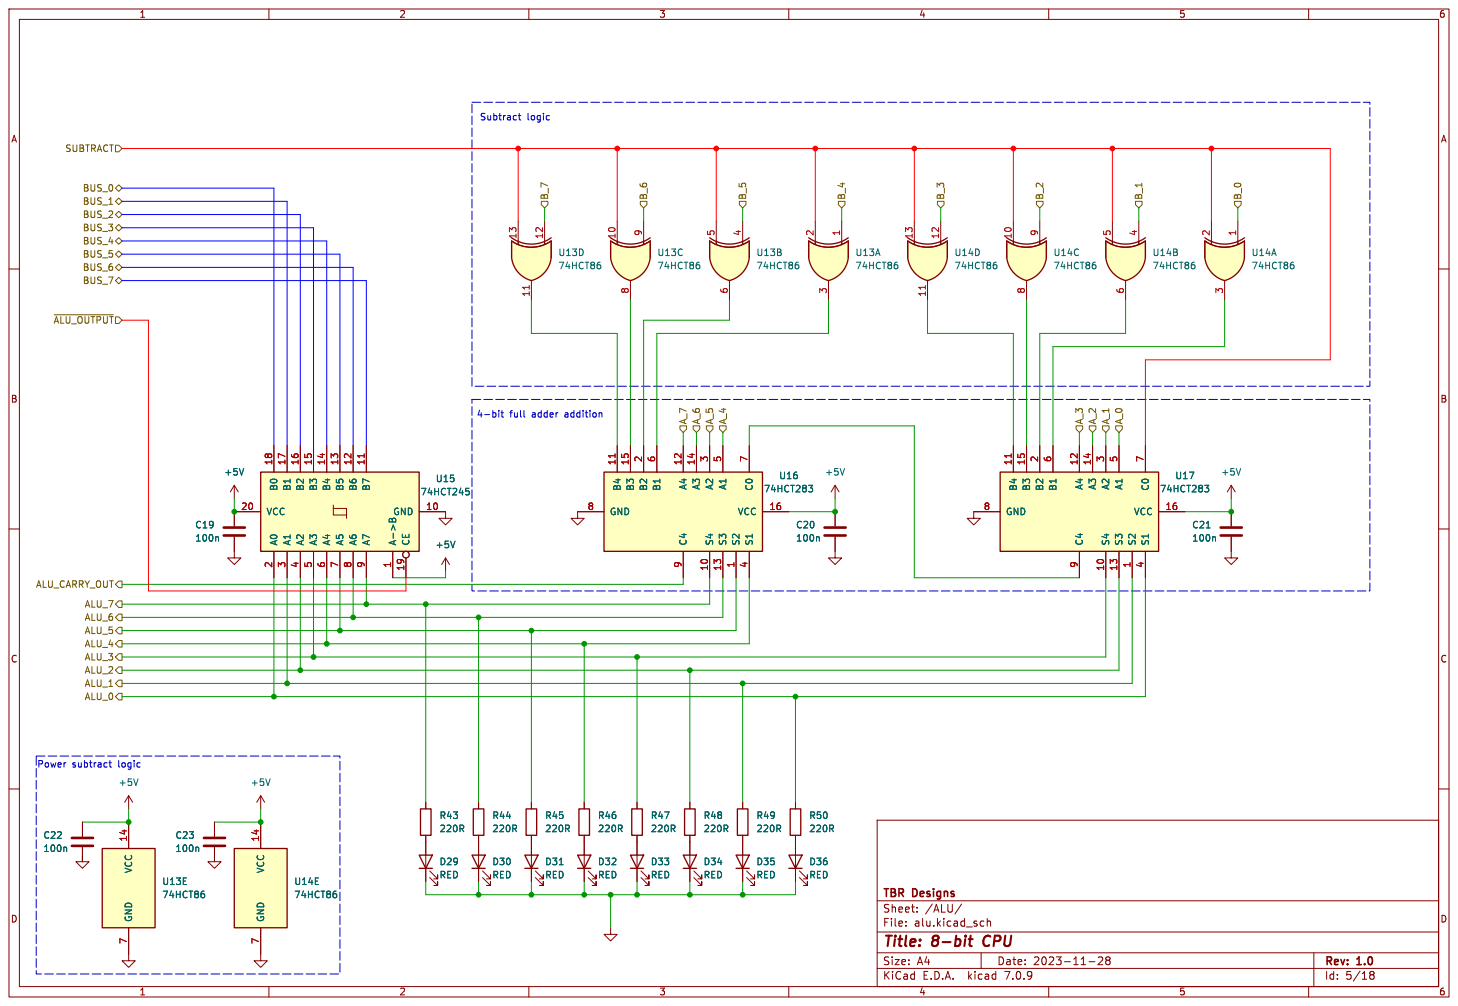
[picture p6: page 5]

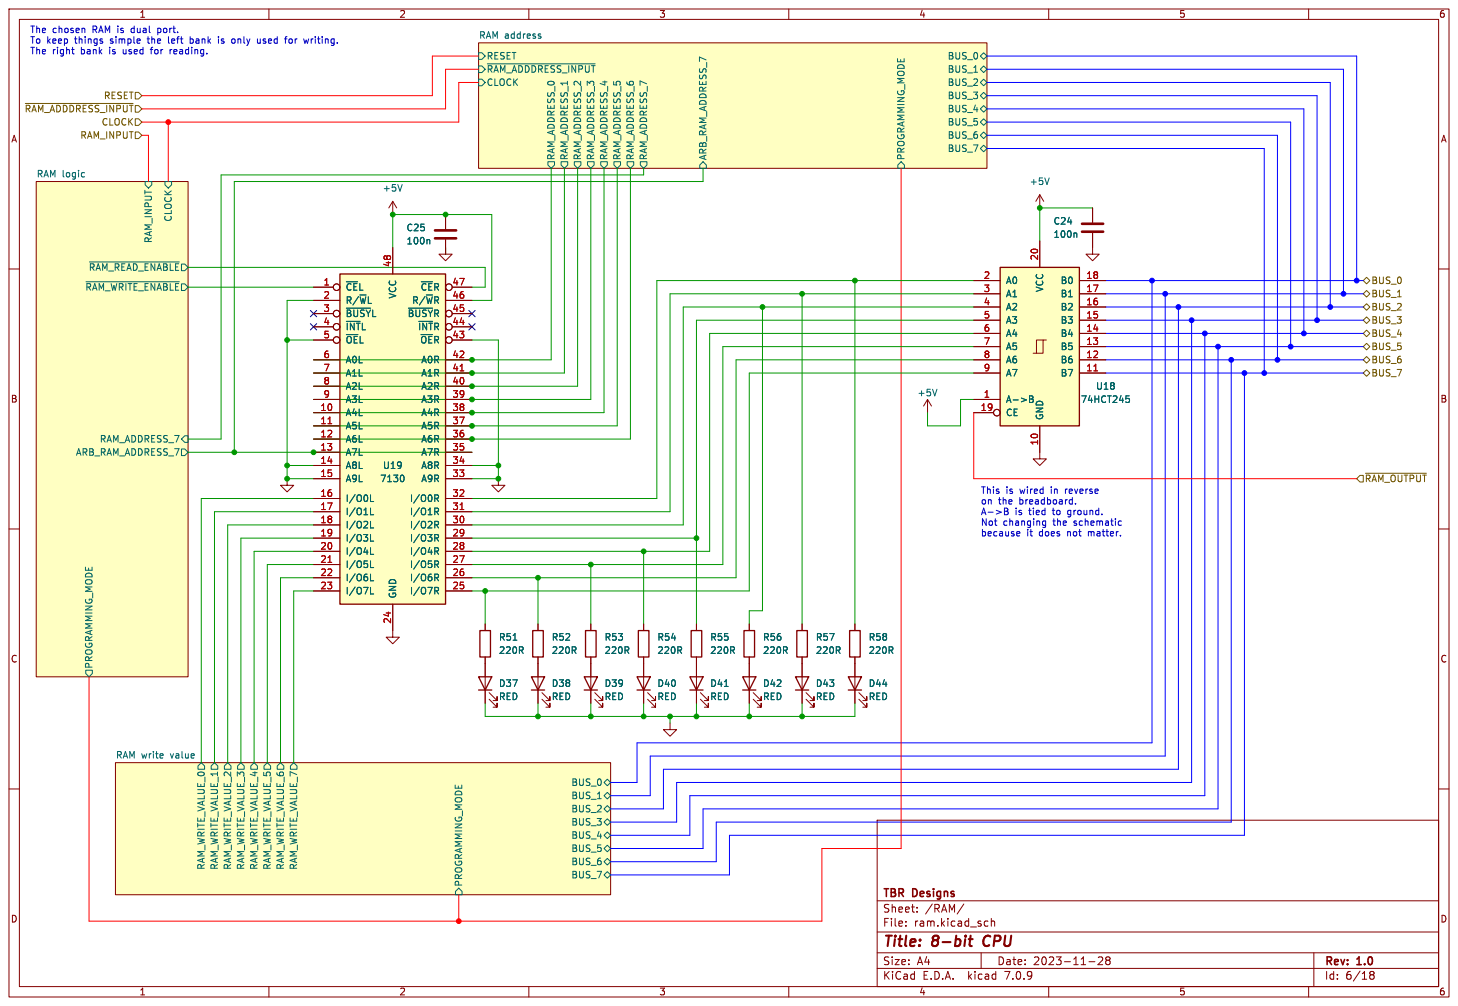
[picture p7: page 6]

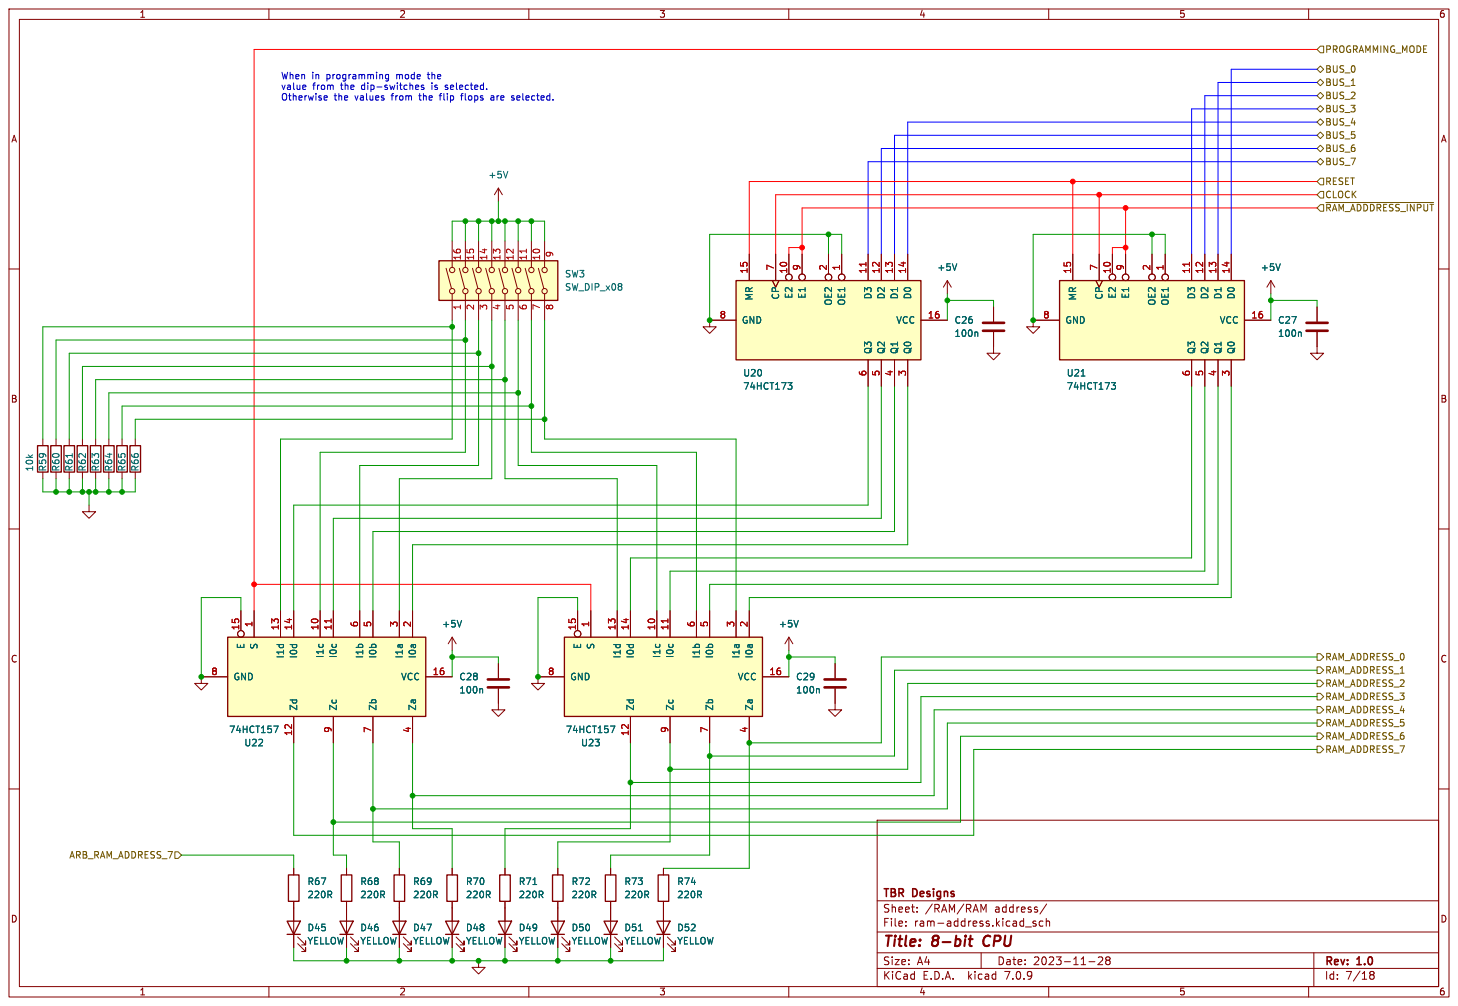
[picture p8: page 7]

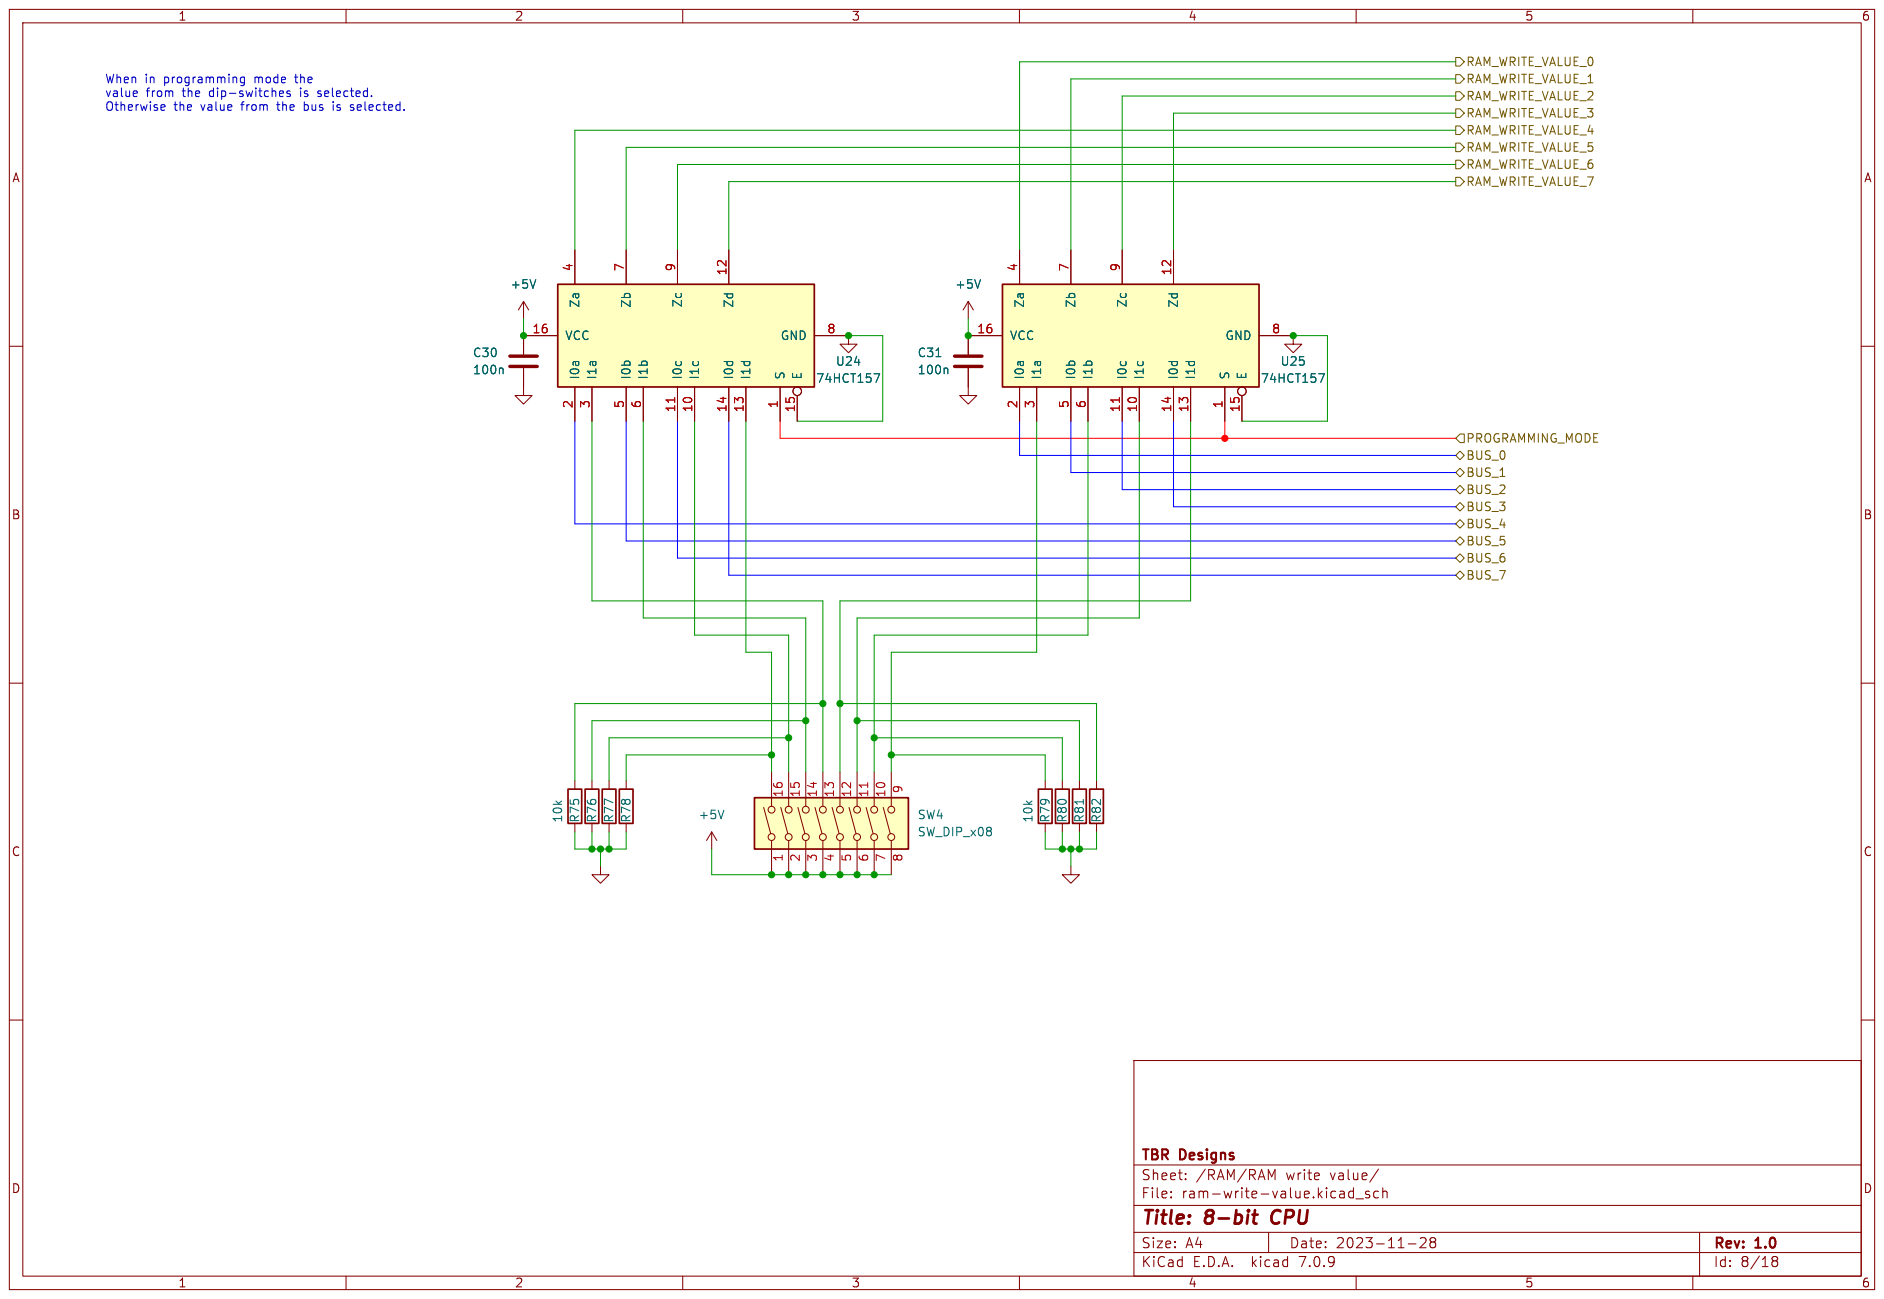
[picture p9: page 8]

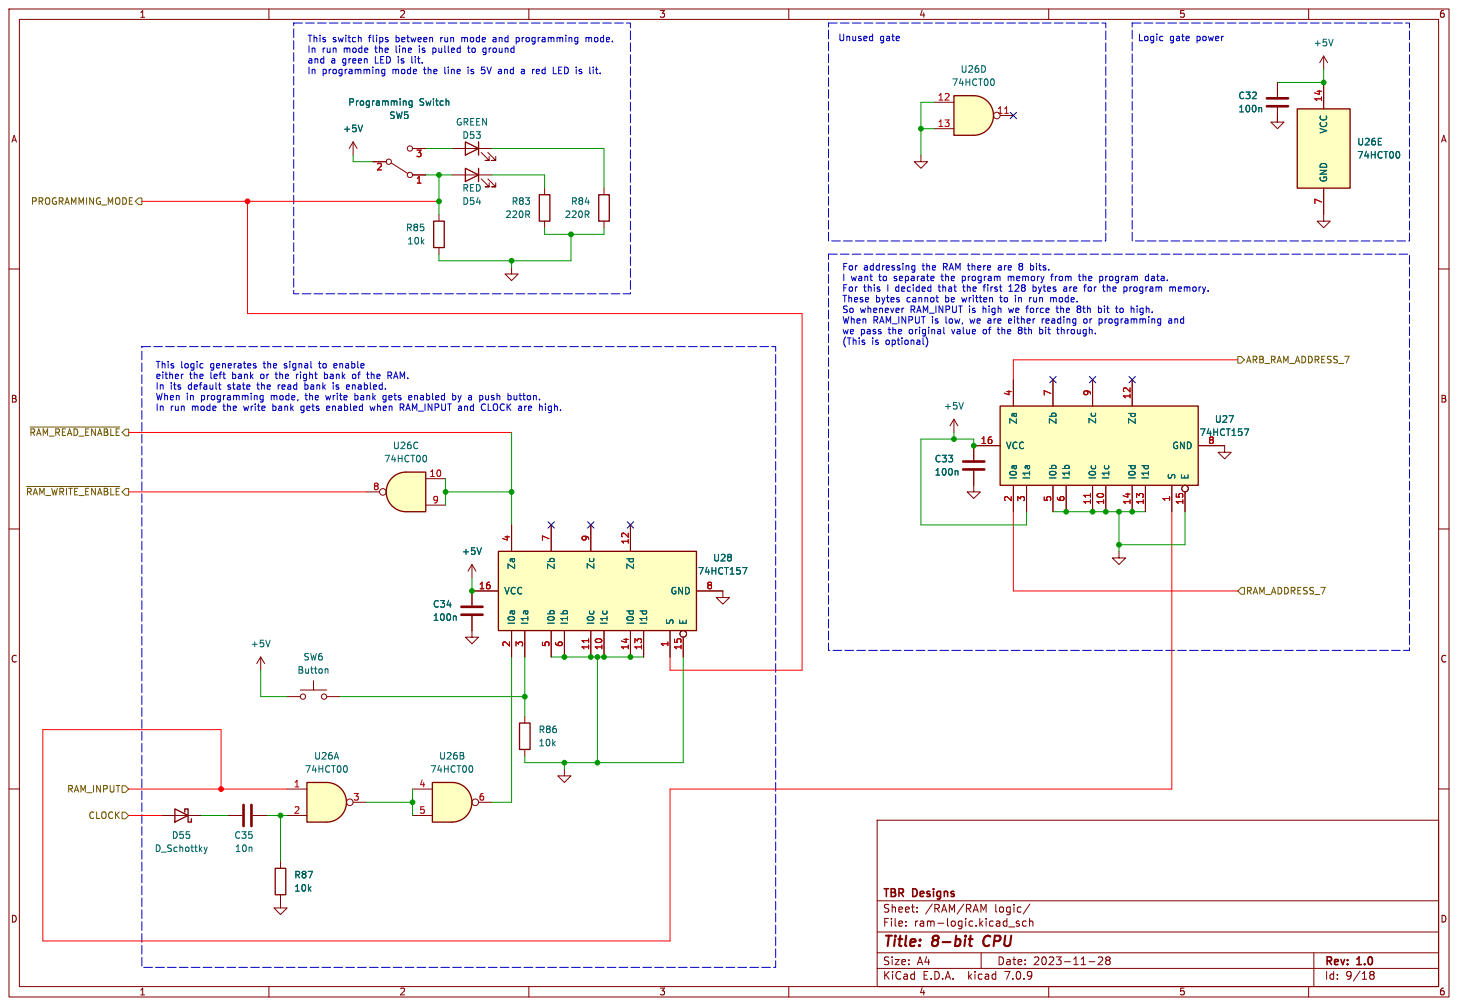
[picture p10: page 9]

In run mode the line is pulled to ground
and a green LED is lit.
~{RAM_READ_ENABLE} PROGRAMMING_MODE

either the left bank or the right bank of the RAM.

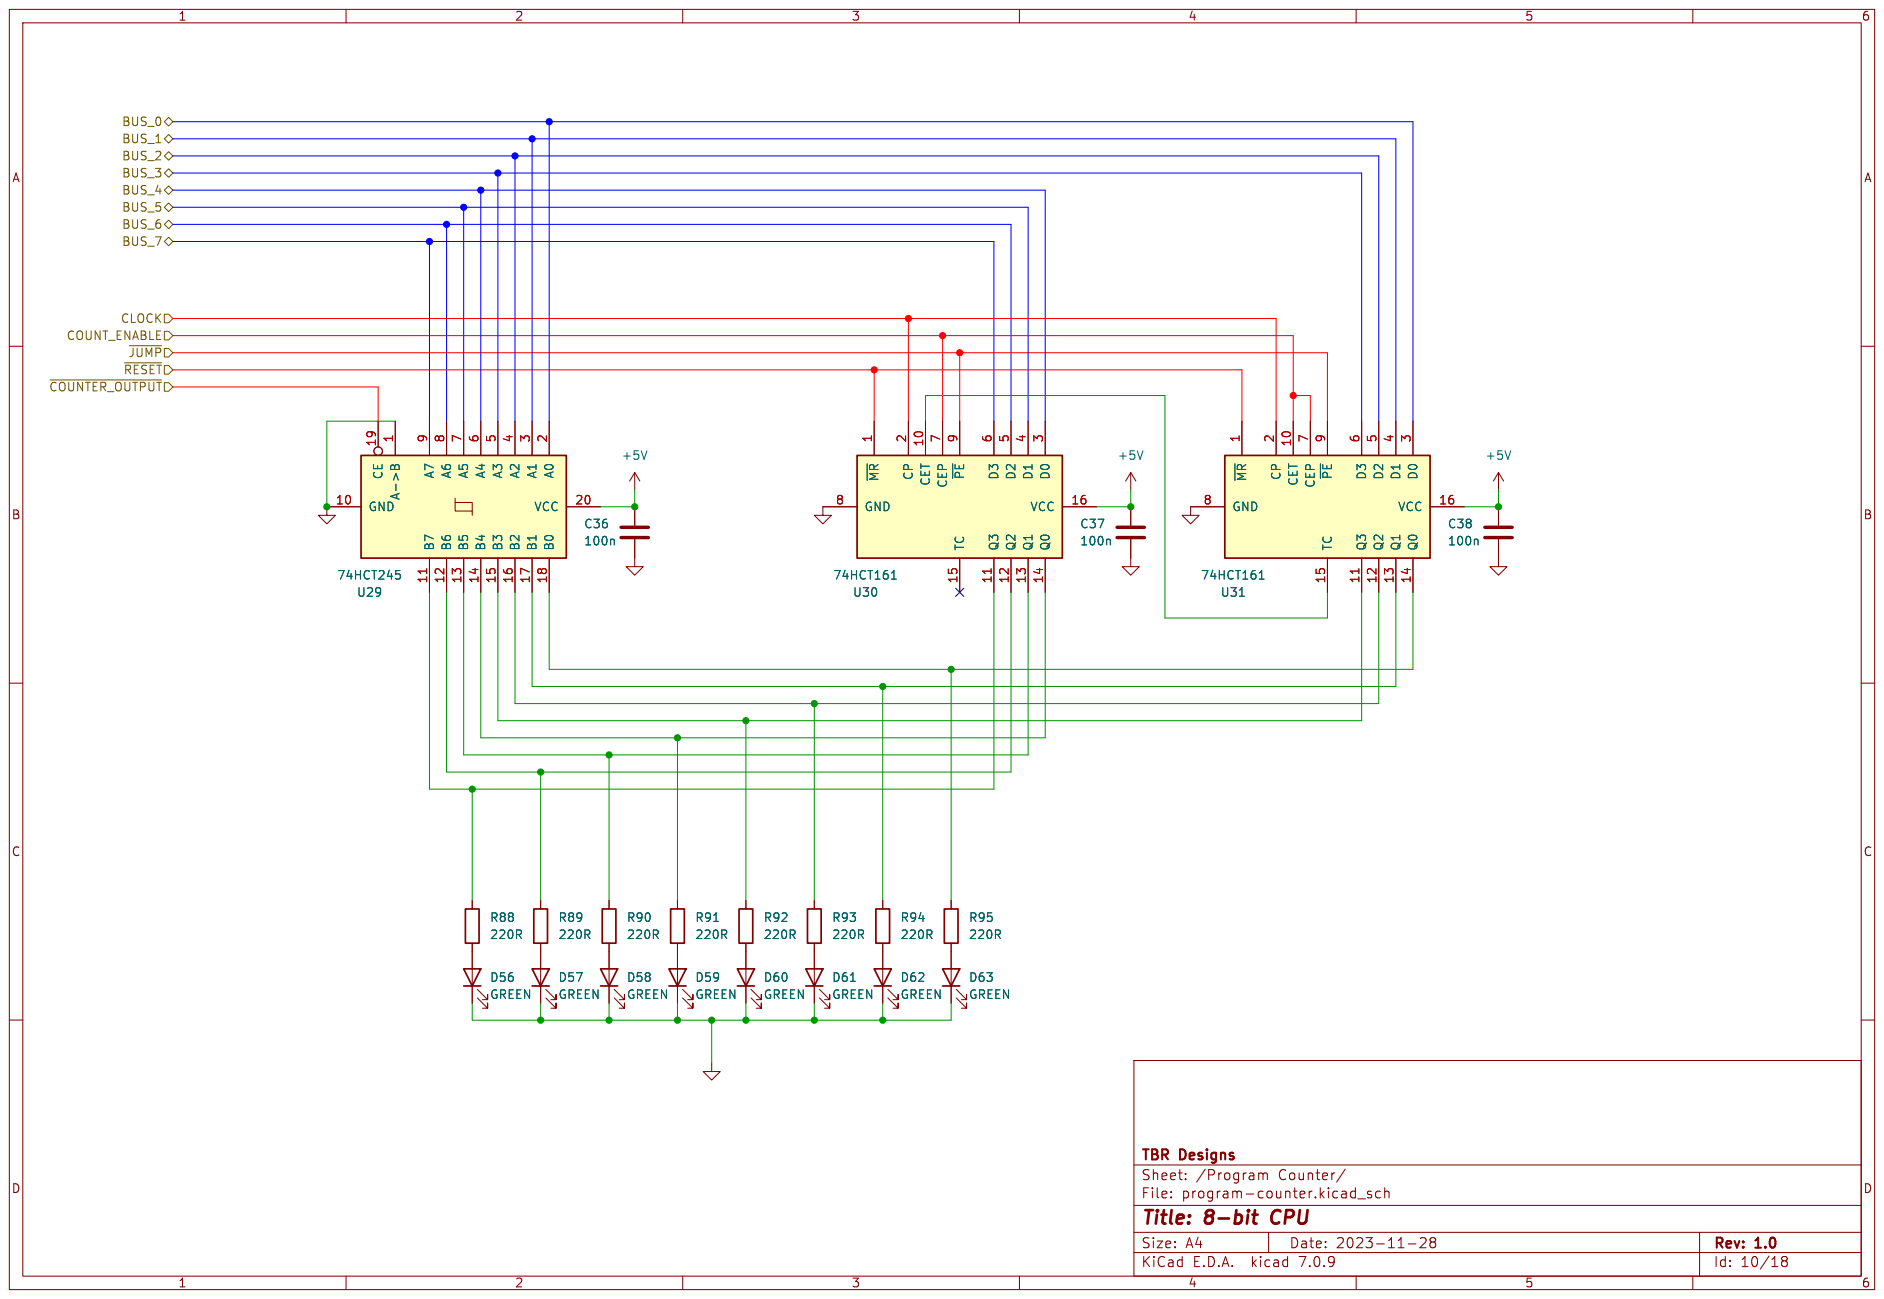
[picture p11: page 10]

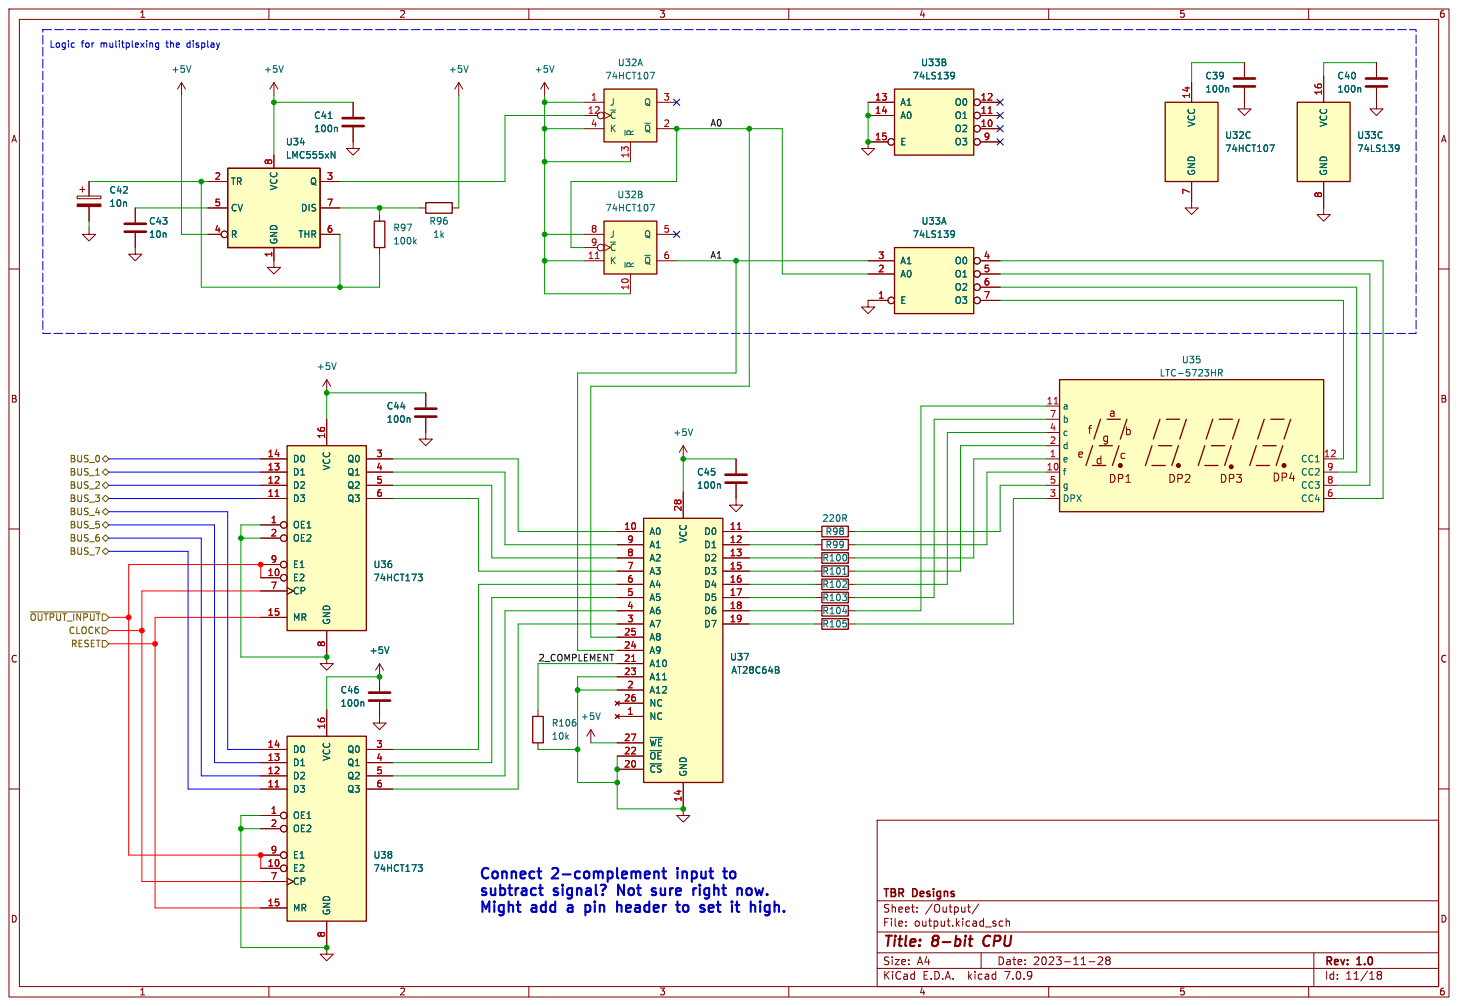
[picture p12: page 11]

subtract signal? Not sure right now. Might add a pin header to set it high.

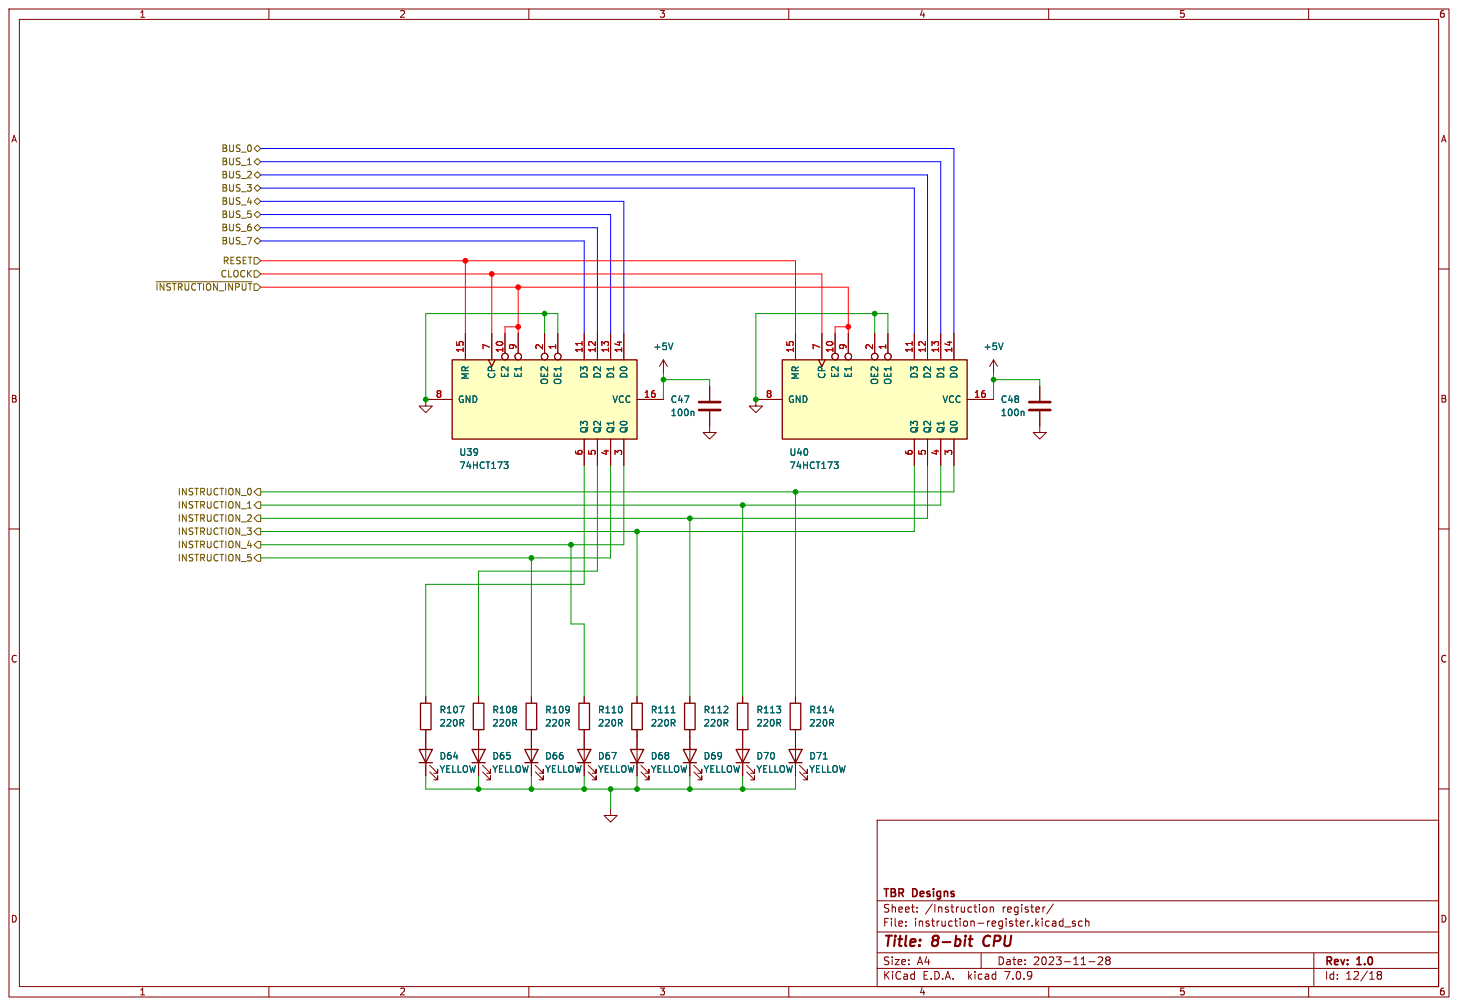
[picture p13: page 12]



Logic gate power D78 GREEN
100n D77 GREEN



2 ~{CS} 20 A10 21 ~{OE}22 A11 23 A9 24 A8 25 NC 26 ~{WE}27 VCC 28 A7

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

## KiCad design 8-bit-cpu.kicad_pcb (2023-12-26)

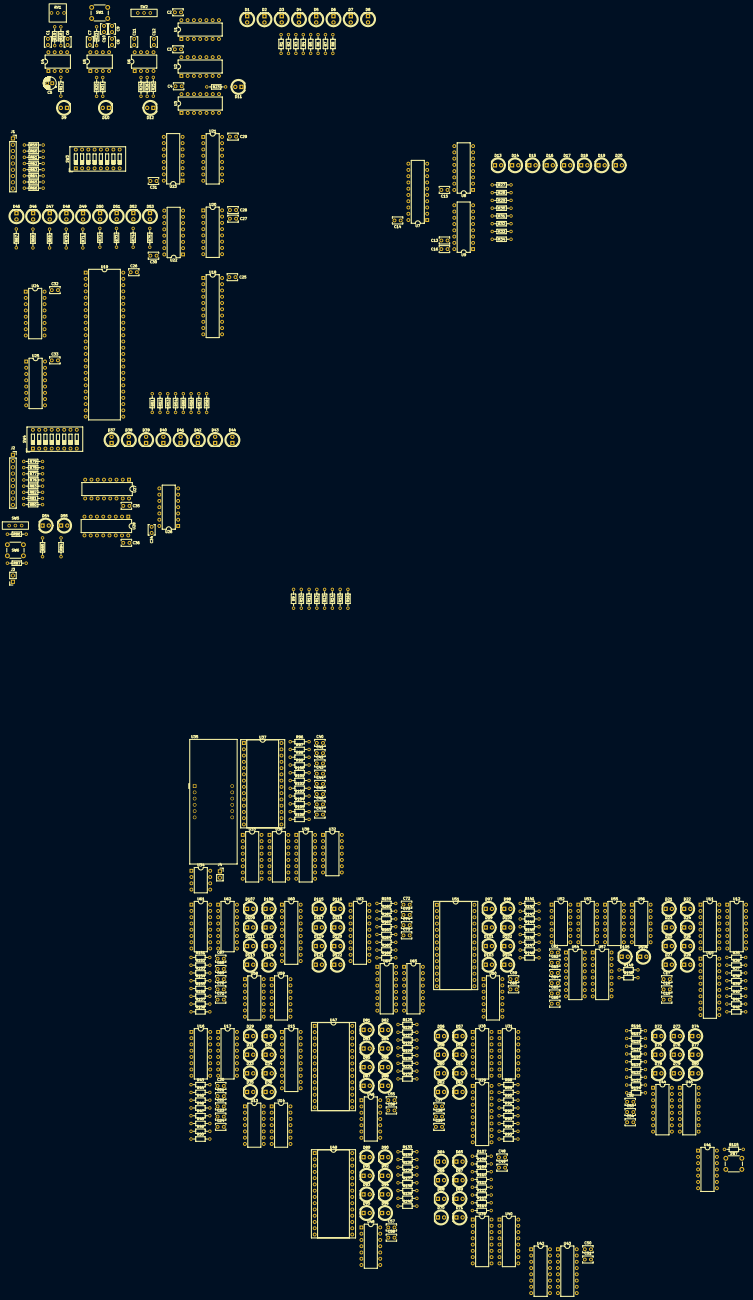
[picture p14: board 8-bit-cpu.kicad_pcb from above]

Board: 2 copper layers, 440 parts (0 on the bottom side), 402 nets, no tracks yet.

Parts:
C1, C2, C3, C4, C7, C9, C10, C11, C14, C15, C16, C17, C18, C19, C20, C21, C22, C23, C24, C25, C26, C28, C29, C30, C31, C32, C33, C34, C35, C36, C37, C38, C39, C40, C41, C42, C45, C46, C47, C48, C49, C50, C51, C52, C53, C54, C55, C56, C57, C58, C59, C60, C61, C62, C63, C64, C65, C66, C67, C68, C69, C70, C71, C73, C74, C75: 100n; C_Disc_D4.0mm_W2.6mm_P2.50mm
C5: 1u; CP_Radial_D5.0mm_P2.00mm
C6, C8, C12, C13, C27, C43, C44, C72: 10n; C_Disc_D4.0mm_W2.6mm_P2.50mm
D1, D2, D3, D4, D5, D6, D7, D8, D13, D14, D15, D16, D17, D18, D19, D20, D21, D22, D23, D24, D25, D26, D27, D28, D29, D30, D31, D32, D33, D34, D35, D36, D37, D38, D39, D40, D41, D42, D43, D44, D55, D72, D73, D74, D107, D108, D109, D110, D111, D112, D113, D114: RED; LED_D5.0mm
D9, D10, D12, D45, D46, D47, D48, D49, D50, D51, D52, D53, D64, D65, D66, D67, D68, D69, D70, D71, D115, D116, D117, D118, D119, D120, D121, D122: YELLOW; LED_D5.0mm
D11, D81, D82, D83, D84, D85, D86, D87, D88, D89, D90, D91, D92, D93, D94, D95, D96, D97, D98, D99, D100, D101, D102, D103, D104: BLUE; LED_D5.0mm
D54, D56, D57, D58, D59, D60, D61, D62, D63, D75, D76, D77, D78, D79, D80, D105, D106: GREEN; LED_D5.0mm
J1: Arduino_Address_Programming_Header; PinSocket_1x09_P2.54mm_Vertical
J2: Arduino_Data_Programming_Header; PinSocket_1x09_P2.54mm_Vertical
J3: Arduino_Programming_Trigger_Header; PinSocket_1x02_P2.54mm_Vertical
J4: 2_Complement_Header; PinSocket_1x02_P2.54mm_Vertical
R1, R2, R3, R4, R5, R6, R7, R8, R17, R21, R23, R26, R27, R28, R29, R30, R31, R32, R33, R34, R35, R36, R37, R38, R39, R40, R41, R42, R43, R44, R45, R46, R47, R48, R49, R50, R51, R52, R53, R54, R55, R56, R57, R58, R67, R68, R69, R70, R71, R72, R73, R74, R75, R84, R85, R88, R89, R90, R91, R92, R93, R94, R95, R98, R99, R100, R101, R102, R103, R104, R105, R107, R108, R109, R110, R111, R112, R113, R114, R116, R117, R118, R119, R120, R121, R122, R123, R124, R125, R126, R127, R128, R129, R130, R131, R132, R133, R134, R135, R136, R137, R138, R139, R140, R141, R142, R143, R144, R145, R146, R147, R148, R149, R150, R151, R152, R153, R154, R155, R156, R157, R158, R159, R160, R161, R162, R163, R164, R165, R166: 220R; R_Axial_DIN0204_L3.6mm_D1.6mm_P7.62mm_Horizontal
R9, R10, R11, R12, R13, R14, R15, R16, R20, R24, R25, R59, R60, R61, R62, R63, R64, R65, R66, R76, R77, R78, R79, R80, R81, R82, R83, R86, R87, R106, R115: 10k; R_Axial_DIN0204_L3.6mm_D1.6mm_P7.62mm_Horizontal
R18, R19, R96: 1k; R_Axial_DIN0204_L3.6mm_D1.6mm_P7.62mm_Horizontal
R22: 1m; R_Axial_DIN0204_L3.6mm_D1.6mm_P7.62mm_Horizontal
R97: 100k; R_Axial_DIN0204_L3.6mm_D1.6mm_P7.62mm_Horizontal
RV1: 1m; Potentiometer_Bourns_3362U_Vertical
SW1, SW6, SW7: Button; SW_PUSH_6mm
SW2: Switch; Mini_Slide_Switch_CUI_THT_123
SW3, SW4: SW_DIP_x08; SW_DIP_SPSTx08_Slide_9.78x22.5mm_W7.62mm_P2.54mm
SW5: Programming Switch; Mini_Slide_Switch_CUI_THT_123
U1, U53, U55: 74HCT08; DIP-14_W7.62mm
U2, U46, U48, U50: 74HCT04; DIP-14_W7.62mm
U3: 74HCT32; DIP-14_W7.62mm
U4, U5, U6, U34: LMC555xN; DIP-8_W7.62mm
U7, U10, U15, U18, U29, U60, U63: 74HCT245; DIP-20_W7.62mm
U8, U9, U11, U12, U20, U21, U36, U38, U39, U40, U42, U43, U57: 74HCT173; DIP-16_W7.62mm
U13, U14: 74HCT86; DIP-14_W7.62mm
U16, U17: 74HCT283; DIP-16_W7.62mm
U19: 7130; DIP-48_W15.24mm
U22, U23, U24, U25, U27, U28, U54: 74HCT157; DIP-16_W7.62mm
U26, U41, U58, U59: 74HCT00; DIP-14_W7.62mm
U30, U31, U45: 74HCT161; DIP-16_W7.62mm
U32: 74HCT107; DIP-14_W7.62mm
U33: 74HCT139; DIP-16_W7.62mm
U35: LTC-5723HR; CA56-12SURKWA
U37, U47, U49, U51: AT28C64B; DIP-28_W15.24mm_Socket
U44: 74HCT138; DIP-16_W7.62mm
U52, U56: 74HCT02; DIP-14_W7.62mm
U61, U62, U64, U65: 74HCT193; DIP-16_W7.62mm

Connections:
+5V: C1.1, C2.1, C3.1, C4.1, C7.1, C11.1, C14.1, C15.1, C16.1, C17.1, C18.1, C19.1, C20.1, C21.1, C22.1, C23.1, C24.1, C25.1, C26.1, C28.1, C29.1, C30.1, C31.1, C32.1, C33.1, C34.1, C35.1, C36.1, C37.1, C38.1, C39.1, C42.1, C45.1, C46.1, C47.1, C48.1, C49.1, C50.1, C51.1, C52.1, C53.1, C54.1, C55.1, C56.1, C57.1, C58.1, C59.1, C60.1, C61.1, C62.1, C63.1, C64.1, C65.1, C66.1, C67.1, C68.1, C69.1, C70.1, C71.1, C73.1, C74.1, C75.1, J4.1, R18.1, R20.1, R22.1, R24.1, R25.1, R96.1, SW3.9, SW3.10, SW3.11, SW3.12, SW3.13, SW3.14, SW3.15, SW3.16, SW4.1, SW4.2, SW4.3, SW4.4, SW4.5, SW4.6, SW4.7, SW4.8, SW5.2 (B), SW6.1, SW7.1, U1.14 (VCC), U2.14 (VCC), U3.14 (VCC), U4.4 (R), U4.8 (VCC), U5.4 (R), U5.8 (VCC), U6.8 (VCC), U7.1 (DIR), U7.20 (VCC), U8.16 (VCC), U9.16 (VCC), U10.1 (DIR), U10.20 (VCC), U11.16 (VCC), U12.16 (VCC), U13.14 (VCC), U14.14 (VCC), U15.1 (DIR), U15.20 (VCC), U16.16 (VCC), U17.16 (VCC), U18.1 (DIR), U18.20 (VCC), U19.46 (R/~WR), U19.48 (VCC), U20.16 (VCC), U21.16 (VCC), U22.16 (VCC), U23.16 (VCC), U24.16 (VCC), U25.16 (VCC), U26.14 (VCC), U27.2 (1A), U27.16 (VCC), U28.16 (VCC), U29.20 (VCC), U30.16 (VCC), U31.16 (VCC), U32.1 (J), U32.4 (K), U32.8 (J), U32.10 (R), U32.11 (K), U32.13 (R), U34.4 (R), U34.8 (VCC), U36.16 (VCC), U37.27 (~WE), U37.28 (VCC), U38.16 (VCC), U39.16 (VCC), U40.16 (VCC), U41.14 (VCC), U42.16 (VCC), U43.16 (VCC), U44.6 (G1), U44.16 (VCC), U45.7 (PE), U45.9 (SPE), U45.10 (TE), U45.16 (VCC), U46.14 (VCC), U47.27 (~WE), U47.28 (VCC), U48.14 (VCC), U49.2 (A12), U49.27 (~WE), U49.28 (VCC), U50.14 (VCC), U51.23 (A11), U51.27 (~WE), U51.28 (VCC), U52.14 (VCC), U53.14 (VCC), U54.16 (VCC), U55.14 (VCC), U56.14 (VCC), U57.16 (VCC), U58.14 (VCC), U59.14 (VCC), U60.1 (DIR), U60.20 (VCC), U61.16 (VCC), U62.16 (VCC), U63.1 (DIR), U63.20 (VCC), U64.11 (~PL), U64.16 (VCC), U65.11 (~PL), U65.16 (VCC)
/A register/A_0: R34.1, U7.2 (A1), U9.3 (Q0), U17.5 (A0)
/A register/A_1: R33.1, U7.3 (A2), U9.4 (Q1), U17.3 (A1)
/A register/A_2: R32.1, U7.4 (A3), U9.5 (Q2), U17.14 (A2)
/A register/A_3: R31.1, U7.5 (A4), U9.6 (Q3), U17.12 (A3)
/A register/A_4: R30.1, U7.6 (A5), U8.3 (Q0), U16.5 (A0)
/A register/A_5: R29.1, U7.7 (A6), U8.4 (Q1), U16.3 (A1)
/A register/A_6: R28.1, U7.8 (A7), U8.5 (Q2), U16.14 (A2)
/A register/A_7: R27.1, U7.9 (A8), U8.6 (Q3), U16.12 (A3)
/A register/CLOCK: R23.1, U1.8, U2.5, U8.7 (CP), U9.7 (CP), U11.7 (CP), U12.7 (CP), U20.7 (CP), U21.7 (CP), U26.2, U30.2 (CP), U31.2 (CP), U36.7 (CP), U38.7 (CP), U57.7 (CP), U58.2, U58.4, U58.10, U58.12, U59.1
/A register/RESET: C13.1, C27.1, C72.1, U8.15 (MR), U9.15 (MR), U11.15 (MR), U12.15 (MR), U20.15 (MR), U21.15 (MR), U36.15 (MR), U38.15 (MR), U39.15 (MR), U40.15 (MR), U41.11, U42.15 (MR), U43.15 (MR), U57.15 (MR), U61.14 (MR), U62.14 (MR), U64.14 (MR), U65.14 (MR)
/A register/~A_INPUT: U8.9 (E1), U8.10 (E2), U9.9 (E1), U9.10 (E2), U46.12
/A register/~A_OUTPUT: U7.19 (OE), U48.2
/ALU/ALU_0: R50.1, U15.2 (A1), U17.4 (S0), U52.12
/ALU/ALU_1: R49.1, U15.3 (A2), U17.1 (S1), U52.11
/ALU/ALU_2: R48.1, U15.4 (A3), U17.13 (S2), U52.9
/ALU/ALU_3: R47.1, U15.5 (A4), U17.10 (S3), U52.8
/ALU/ALU_4: R46.1, U15.6 (A5), U16.4 (S0), U52.6
/ALU/ALU_5: R45.1, U15.7 (A6), U16.1 (S1), U52.5
/ALU/ALU_6: R44.1, U15.8 (A7), U16.13 (S2), U52.3
/ALU/ALU_7: R43.1, U15.9 (A8), U16.10 (S3), U52.2
/ALU/ALU_CARRY_OUT: U16.9 (C_{OUT}), U57.14 (D0)
/ALU/B_0: R42.1, U10.2 (A1), U12.3 (Q0), U14.1
/ALU/B_1: R41.1, U10.3 (A2), U12.4 (Q1), U14.4
/ALU/B_2: R40.1, U10.4 (A3), U12.5 (Q2), U14.9
/ALU/B_3: R39.1, U10.5 (A4), U12.6 (Q3), U14.12
/ALU/B_4: R38.1, U10.6 (A5), U11.3 (Q0), U13.1
/ALU/B_5: R37.1, U10.7 (A6), U11.4 (Q1), U13.4
/ALU/B_6: R36.1, U10.8 (A7), U11.5 (Q2), U13.9
/ALU/B_7: R35.1, U10.9 (A8), U11.6 (Q3), U13.12
/ALU/SUBTRACT: R140.1, U13.2, U13.5, U13.10, U13.13, U14.2, U14.5, U14.10, U14.13, U17.7 (C_{IN}), U49.19 (D7)
/ALU/~ALU_OUTPUT: U15.19 (OE), U48.4, U54.1 (~A/B)
/B register/~B_INPUT: U11.9 (E1), U11.10 (E2), U12.9 (E1), U12.10 (E2), U48.6
/B register/~B_OUTPUT: U10.19 (OE), U48.8
/BUS_0: R8.2, R16.1, U7.18 (B1), U9.14 (D0), U10.18 (B1), U12.14 (D0), U15.18 (B1), U18.18 (B1), U21.14 (D0), U25.2 (1A), U29.2 (A1), U31.3 (P0), U36.14 (D0), U40.14 (D0), U60.18 (B1), U62.15 (P0), U63.18 (B1)
/BUS_1: R7.2, R15.1, U7.17 (B2), U9.13 (D1), U10.17 (B2), U12.13 (D1), U15.17 (B2), U18.17 (B2), U21.13 (D1), U25.5 (2A), U29.3 (A2), U31.4 (P1), U36.13 (D1), U40.13 (D1), U60.17 (B2), U62.1, U63.17 (B2)
/BUS_2: R6.2, R14.1, U7.16 (B3), U9.12 (D2), U10.16 (B3), U12.12 (D2), U15.16 (B3), U18.16 (B3), U21.12 (D2), U25.11 (3A), U29.4 (A3), U31.5 (P2), U36.12 (D2), U40.12 (D2), U60.16 (B3), U62.10 (P2), U63.16 (B3)
/BUS_3: R5.2, R13.1, U7.15 (B4), U9.11 (D3), U10.15 (B4), U12.11 (D3), U15.15 (B4), U18.15 (B4), U21.11 (D3), U25.14 (4A), U29.5 (A4), U31.6 (P3), U36.11 (D3), U40.11 (D3), U60.15 (B4), U62.9 (P3), U63.15 (B4)
/BUS_4: R4.2, R12.1, U7.14 (B5), U8.14 (D0), U10.14 (B5), U11.14 (D0), U15.14 (B5), U18.14 (B5), U20.14 (D0), U24.2 (1A), U29.6 (A5), U30.3 (P0), U38.14 (D0), U39.14 (D0), U60.14 (B5), U61.15 (P0), U63.14 (B5)
/BUS_5: R3.2, R11.1, U7.13 (B6), U8.13 (D1), U10.13 (B6), U11.13 (D1), U15.13 (B6), U18.13 (B6), U20.13 (D1), U24.5 (2A), U29.7 (A6), U30.4 (P1), U38.13 (D1), U39.13 (D1), U60.13 (B6), U61.1, U63.13 (B6)
/BUS_6: R2.2, R10.1, U7.12 (B7), U8.12 (D2), U10.12 (B7), U11.12 (D2), U15.12 (B7), U18.12 (B7), U20.12 (D2), U24.11 (3A), U29.8 (A7), U30.5 (P2), U38.12 (D2), U39.12 (D2), U60.12 (B7), U61.10 (P2), U63.12 (B7)
/BUS_7: R1.2, R9.1, U7.11 (B8), U8.11 (D3), U10.11 (B8), U11.11 (D3), U15.11 (B8), U18.11 (B8), U20.11 (D3), U24.14 (4A), U29.9 (A8), U30.6 (P3), U38.11 (D3), U39.11 (D3), U60.11 (B8), U61.9 (P3), U63.11 (B8)
/CPU flags/ALU_ZERO: U53.8, U54.14 (4A)
/CPU flags/CARRY_FLAG: D106.2 (A), U42.12 (D2), U57.3 (Q0)
/CPU flags/X_0: R158.1, U56.2, U60.2 (A1), U62.3 (Q0)
/CPU flags/X_1: R157.1, U56.3, U60.3 (A2), U62.2 (Q1)
/CPU flags/X_2: R156.1, U56.5, U60.4 (A3), U62.6 (Q2)
/CPU flags/X_3: R155.1, U56.6, U60.5 (A4), U62.7 (Q3)
/CPU flags/X_4: R154.1, U56.8, U60.6 (A5), U61.3 (Q0)
/CPU flags/X_5: R153.1, U56.9, U60.7 (A6), U61.2 (Q1)
/CPU flags/X_6: R152.1, U56.11, U60.8 (A7), U61.6 (Q2)
/CPU flags/X_7: R151.1, U56.12, U60.9 (A8), U61.7 (Q3)
/CPU flags/X_ZERO: U54.13 (4B), U55.8
/CPU flags/ZERO_FLAG: D105.2 (A), U42.11 (D3), U57.4 (Q1)
/CPU flags/~FLAGS_INPUT: U48.12, U57.9 (E1), U57.10 (E2)
/Clock/ASTABLE_CLOCK: U1.3, U3.1
/Clock/ASTABLE_OUTPUT: R17.1, U1.1, U4.3 (Q)
/Clock/BISTABLE_OUTPUT: R26.1, U1.2, U2.3, U6.3 (Q)
/Clock/HALT: R139.1, U2.1, U49.18 (D6)
/Clock/MONOSTABLE_CLOCK: U1.6, U3.2
/Clock/MONOSTABLE_OUTPUT: R21.1, U1.4, U5.3 (Q)
/Clock/SELECTED_CLOCK: U1.9, U3.3
/Clock/~BISTABLE_OUTPUT: U1.5, U2.4
/Clock/~CLOCK: U2.6, U39.7 (CP), U40.7 (CP), U42.7 (CP), U43.7 (CP), U45.2 (CP)
/Clock/~HALT: U1.10, U2.2
/Control logic/COUNT_ENABLE: R132.1, U30.7 (PE), U31.7 (PE), U31.10 (TE), U47.19 (D7)
/Control logic/DEC: R147.1, U51.18 (D6), U58.5
/Control logic/EEPROM address buffer/EEPROM_3: U43.3 (Q0), U47.7 (A3), U49.7 (A3), U51.7 (A3)
/Control logic/EEPROM address buffer/EEPROM_4: U43.4 (Q1), U47.6 (A4), U49.6 (A4), U51.6 (A4)
/Control logic/EEPROM address buffer/EEPROM_5: U43.5 (Q2), U47.5 (A5), U49.5 (A5), U51.5 (A5)
/Control logic/EEPROM address buffer/EEPROM_6: U43.6 (Q3), U47.4 (A6), U49.4 (A6), U51.4 (A6)
/Control logic/EEPROM address buffer/EEPROM_7: U42.3 (Q0), U47.3 (A7), U49.3 (A7), U51.3 (A7)
/Control logic/EEPROM address buffer/EEPROM_8: U42.4 (Q1), U47.25 (A8), U49.25 (A8), U51.25 (A8)
/Control logic/EEPROM address buffer/EEPROM_9: U42.5 (Q2), U47.24 (A9), U49.24 (A9), U51.24 (A9)
/Control logic/EEPROM address buffer/EEPROM_10: U42.6 (Q3), U47.21 (A10), U49.21 (A10), U51.21 (A10)
/Control logic/INC: R148.1, U51.19 (D7), U58.1
/Control logic/INSTRUCTION_0: R114.1, U40.3 (Q0), U43.14 (D0)
/Control logic/INSTRUCTION_1: R113.1, U40.4 (Q1), U43.13 (D1)
/Control logic/INSTRUCTION_2: R112.1, U40.5 (Q2), U43.12 (D2)
/Control logic/INSTRUCTION_3: R111.1, U40.6 (Q3), U43.11 (D3)
/Control logic/INSTRUCTION_4: R110.1, U39.3 (Q0), U42.14 (D0)
/Control logic/INSTRUCTION_5: R109.1, U39.4 (Q1), U42.13 (D1)
/Control logic/Left Microcode EEPROM/MS_0: D74.2 (A), U44.1 (A), U45.14 (Q0), U47.10 (A0), U49.10 (A0), U51.10 (A0)
/Control logic/Left Microcode EEPROM/MS_1: D73.2 (A), U44.2 (B), U45.13 (Q1), U47.9 (A1), U49.9 (A1), U51.9 (A1)
/Control logic/Left Microcode EEPROM/MS_2: D72.2 (A), U44.3 (C), U45.12 (Q2), U47.8 (A2), U49.8 (A2), U51.8 (A2)
/Control logic/POP_STACK: R145.1, U51.16 (D4), U58.13
/Control logic/PUSH_STACK: R146.1, U51.17 (D5), U58.9
/Control logic/RAM_INPUT: R131.1, U26.1, U26.13, U47.18 (D6)
/Control logic/STACK_ADDRESS: R144.1, U28.14 (4A), U50.5, U51.15 (D3)
/Control logic/X_INPUT: R142.1, U51.12 (D1), U59.2
/Control logic/~COUNTER_OUTPUT: U29.19 (OE), U46.10
/Control logic/~INSTRUCTION_INPUT: U39.9 (E1), U39.10 (E2), U40.9 (E1), U40.10 (E2), U46.6
/Control logic/~JUMP: U30.9 (SPE), U31.9 (SPE), U46.8
/Control logic/~OUTPUT_INPUT: U36.9 (E1), U36.10 (E2), U38.9 (E1), U38.10 (E2), U48.10
/Control logic/~RAM_ADDDRESS_INPUT: U20.9 (E1), U20.10 (E2), U21.9 (E1), U21.10 (E2), U46.2
/Control logic/~RAM_OUTPUT: U18.19 (OE), U46.4
/Control logic/~RESET: U30.1 (MR), U31.1 (MR), U41.1, U41.8, U41.12, U41.13
/Control logic/~STACK_ADDRESS: U26.12, U50.6
/Control logic/~STACK_OUTPUT: U50.8, U63.19 (OE)
/Control logic/~X_OUTPUT: U50.12, U60.19 (OE)
/Output/2_COMPLEMENT: J4.2, R106.1, U37.21 (A10)
/Output/A0: U32.2 (~Q), U32.9 (C), U33.2 (A), U37.25 (A8)
/Output/A1: U32.6 (~Q), U33.3 (B), U37.24 (A9)
/RAM/RAM address/ARB_RAM_ADDRESS_7: R68.1, U19.13 (A7L), U19.35 (A7R), U27.4 (1Y)
/RAM/RAM address/ARB_STACK_ADDRESS: R67.1, U19.14 (A8L), U19.34 (A8R), U28.12 (4Y)
/RAM/RAM address/PROGRAMMING_MODE: D55.2 (A), R86.1, SW5.1 (A), U22.1 (~A/B), U23.1 (~A/B), U24.1 (~A/B), U25.1 (~A/B), U28.1 (~A/B)
/RAM/RAM address/RAM_ADDRESS_0: R75.1, U19.6 (A0L), U19.42 (A0R), U23.4 (1Y)
/RAM/RAM address/RAM_ADDRESS_1: R74.1, U19.7 (A1L), U19.41 (A1R), U23.7 (2Y)
/RAM/RAM address/RAM_ADDRESS_2: R73.1, U19.8 (A2L), U19.40 (A2R), U23.9 (3Y)
/RAM/RAM address/RAM_ADDRESS_3: R72.1, U19.9 (A3L), U19.39 (A3R), U23.12 (4Y)
/RAM/RAM address/RAM_ADDRESS_4: R71.1, U19.10 (A4L), U19.38 (A4R), U22.4 (1Y)
/RAM/RAM address/RAM_ADDRESS_5: R70.1, U19.11 (A5L), U19.37 (A5R), U22.7 (2Y)
/RAM/RAM address/RAM_ADDRESS_6: R69.1, U19.12 (A6L), U19.36 (A6R), U22.9 (3Y)
/RAM/RAM address/RAM_ADDRESS_7: U22.12 (4Y), U27.3 (1B)
/RAM/RAM logic/~RAM_READ_ENABLE: U19.47 (~CER), U26.9, U26.10, U28.4 (1Y)
/RAM/RAM logic/~RAM_WRITE_ENABLE: U19.1 (~CEL), U26.8
/RAM/RAM write value/RAM_WRITE_VALUE_0: U19.16 (I/O0L), U25.4 (1Y)
/RAM/RAM write value/RAM_WRITE_VALUE_1: U19.17 (I/O1L), U25.7 (2Y)
/RAM/RAM write value/RAM_WRITE_VALUE_2: U19.18 (I/O2L), U25.9 (3Y)
/RAM/RAM write value/RAM_WRITE_VALUE_3: U19.19 (I/O3L), U25.12 (4Y)
/RAM/RAM write value/RAM_WRITE_VALUE_4: U19.20 (I/O4L), U24.4 (1Y)
/RAM/RAM write value/RAM_WRITE_VALUE_5: U19.21 (I/O5L), U24.7 (2Y)
/RAM/RAM write value/RAM_WRITE_VALUE_6: U19.22 (I/O6L), U24.9 (3Y)
/RAM/RAM write value/RAM_WRITE_VALUE_7: U19.23 (I/O7L), U24.12 (4Y)
/Stack/DEC_STACK: U58.11, U65.4 (CPD)
/Stack/INC_STACK: U58.8, U65.5 (CPU)
/X Register/DEC_X: U58.6, U62.4 (CPD)
/X Register/INC_X: U58.3, U62.5 (CPU)
/X Register/X_INPUT_TRG: U59.3, U61.11 (~PL), U62.11 (~PL)
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

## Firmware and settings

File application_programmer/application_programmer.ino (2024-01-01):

#define NOP 0b00000000
#define LDA 0b00000001
#define ADD 0b00000010
#define SUB 0b00000011
#define STA 0b00000100
#define LDI 0b00000101
#define JMP 0b00000110
#define JC 0b00000111
#define JZ 0b00001000
#define LDB 0b00001001
#define STB 0b00001010
#define LDIB 0b00001011
#define OUT 0b00001100
#define OUTB 0b00001101
#define OUTX 0b00001110
#define HLT 0b00001111
#define LDX 0b00010000
#define STX 0b00010001
#define LDIX 0b00010010
#define PSH 0b00010011
#define POP 0b00010100
#define PSHB 0b00010101
#define POPB 0b00010110
#define JSR 0b00010111
#define RTS 0b00011000
#define INCX 0b00011001
#define DECX 0b00011010

const int ADDRESS_PINS[8] = { 2, 3, 4, 5, 6, 7, 8, 9 };  // D2, D3, D4, D5, D6, D7, D8, D9
#define WRITE_PIN 10                                 // D10

int instructionCounter = 0;
int dataCounter = 0;
const int dataOffset = 128;

void setup() {
  Serial.begin(57600);

  pinMode(WRITE_PIN, OUTPUT);
  digitalWrite(WRITE_PIN, LOW);
  for (int i = 0; i < 9; i++) {
    pinMode(ADDRESS_PINS[i], OUTPUT);
    digitalWrite(ADDRESS_PINS[i], LOW);
  }

  pinMode(A7, OUTPUT);
  digitalWrite(A7, LOW);
  pinMode(A6, OUTPUT);
  digitalWrite(A6, LOW);
  pinMode(A5, OUTPUT);
  digitalWrite(A5, LOW);
  pinMode(A4, OUTPUT);
  digitalWrite(A4, LOW);
  pinMode(A3, OUTPUT);
  digitalWrite(A3, LOW);
  pinMode(A2, OUTPUT);
  digitalWrite(A2, LOW);
  pinMode(A1, OUTPUT);
  digitalWrite(A1, LOW);
  pinMode(A0, OUTPUT);
  digitalWrite(A0, LOW);

  //fibonacci();
  fibonacciInstructionCounter();
}

void loop() {
  readSerial();
}

void resetCounters() {
  instructionCounter = 0;
  dataCounter = 0;
}

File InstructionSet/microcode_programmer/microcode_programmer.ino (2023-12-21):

#define DATA 2
#define CLOCK 3
#define LATCH 4
#define EEPROM_D0 5
#define EEPROM_D7 12
#define WRITE_EN 13
#define OUTPUT_EN A0

bool DEBUG = false;
bool available = true;

void setup() {
  Serial.begin(57600);
  pinMode(DATA, OUTPUT);
  pinMode(CLOCK, OUTPUT);
  pinMode(LATCH, OUTPUT);
  pinMode(WRITE_EN, OUTPUT);
  pinMode(OUTPUT_EN, OUTPUT);

  digitalWrite(WRITE_EN, HIGH);
  digitalWrite(OUTPUT_EN, LOW);
}

void loop() {
  readSerial();
}

void setAddress(int address) {
  shiftOut(DATA, CLOCK, MSBFIRST, address);
  shiftOut(DATA, CLOCK, MSBFIRST, (address >> 8));

  digitalWrite(LATCH, LOW);
  digitalWrite(LATCH, HIGH);
  digitalWrite(LATCH, LOW);
}

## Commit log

2023-12-10 ram address 7 led now uses the arbitrated signal
    [ram-address.kicad_sch, ram-logic.kicad_sch, ram.kicad_sch]
2023-12-11 finished the control logic
    [8-bit-cpu.kicad_sch, control-logic.kicad_sch, cpu-flags.kicad_sch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]
2023-12-11 redid the eeprom
    [control-logic.kicad_sch, cpu-flags.kicad_sch, instruction-register.kicad_sch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]
2023-12-12 add pdf for instructions
    [left-microcode-eeprom.kicad_sch, middle-microcode-eeprom.kicad_sch, right-microcode-eeprom.kicad_sch]
2023-12-13 some rerouting
    [8-bit-cpu.kicad_sch]
2023-12-13 fixed gate type in cpu flags
    [cpu-flags.kicad_sch]
2023-12-16 Fixed out instructions, no CE. Added note about RESET line in RaI
    [cpu-flags.kicad_sch, ram-address.kicad_sch]
2023-12-16 added stack and x register. Added logic for stack_address so ram address 7 gets passes and ram address 8 is high
    [8-bit-cpu.kicad_sch, control-logic.kicad_sch, cpu-flags.kicad_sch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]
2023-12-17 changed symbols
    [8-bit-cpu.kicad_sch, a-register.kicad_sch, alu.kicad_sch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]
2023-12-17 some cleanup
    [control-logic.kicad_sch, cpu-flags.kicad_sch, instruction-register.kicad_sch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]
2023-12-18 added arduino code to program the cpu
2023-12-18 add arduino headers for programming
    [8-bit-cpu.kicad_pcb, control-logic.kicad_sch, cpu-flags.kicad_sch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]
2023-12-20 trying to solve issues
    [8-bit-cpu.kicad_sch, a-register.kicad_sch, alu.kicad_sch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]
2023-12-21 it kinda works
    [ram-logic.kicad_sch]
2023-12-21 fixed push address, push pop tested, fibonacci loops correctly
    [stack.kicad_sch]
2023-12-22 added breadboard layout
    [8-bit-cpu.kicad_sch, breadboard-layout.kicad_sch, control-logic.kicad_sch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]
2023-12-22 regenerated BOM
    [8-bit-cpu.csv, a-register.kicad_sch, ram-address.kicad_sch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]
2023-12-28 alu carry out goes through selector now so we do not set the carry flag when we do incx or decx
    [cpu-flags.kicad_sch]
2023-12-28 some more layout
    [alu.kicad_sch, b-register.kicad_sch, control-logic.kicad_sch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]
2023-12-30 kicad update
    [8-bit-cpu.kicad_sch, a-register.kicad_sch, alu.kicad_sch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]
